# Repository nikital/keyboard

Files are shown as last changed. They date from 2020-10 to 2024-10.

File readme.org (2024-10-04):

#+STARTUP: indent

* Layout
Generated at http://www.keyboard-layout-editor.com/

* Plate
Generated at http://builder.swillkb.com/
- Switch Type: MX
- Stabilizer: Cherry Only

* PCB

** Placement
5.7mm 7.5mm For diodes from pin 1

** Components

*** MCU
ATMEGA32U4-AU

*** PPTC
MF-PSMF020X-2

*** I/O expander
MCP23018-E/SO

*** Resistors (2012/0805)

*** ESD protection
PRTR5V0U2X

* Burn
Load DFU bootloader. When using Arduino as ISP, first burn an Arduino using the
ArduinoISP example sketch. Then wire everything according to comments. Make sure
to use a good 5V source and the the 5V on ICSP (not sure why, but it glitched).
Then run:
#+begin_src sh
avrdude -patmega32u4 -cstk500v1 -P/dev/ttyUSB0 -b19200 -e -U flash:w:dfu/ATMega32U4-usbdevice_dfu-1_0_0.hex:i -U lfuse:w:0b01011110:m -U hfuse:w:0b10011001:m -U efuse:w:0b11000011:m -U lock:w:0b101100:m
#+end_src

If using a USBasp based programmer, use: =-cusbasp=.
#+begin_src sh
avrdude -patmega32u4 -cusbasp -e -U flash:w:dfu/ATMega32U4-usbdevice_dfu-1_0_0.hex:i -U lfuse:w:0b01011110:m -U hfuse:w:0b10011001:m -U efuse:w:0b11000011:m -U lock:w:0b101100:m
#+end_src

Make sure to issue an ~dfu-programmer atmega32u4 erase --force~ to make sure that the flash
is writable.

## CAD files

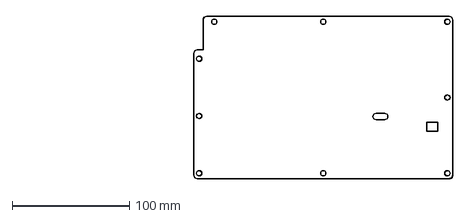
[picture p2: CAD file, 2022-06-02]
plate/slash_production/acryl_1_5_mm/right_acryl_1_5_mm.dxf
372.5 x 138.5 mm

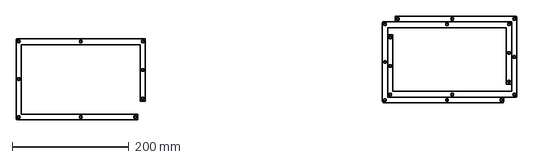
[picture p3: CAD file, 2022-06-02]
plate/slash_production/acryl_4_mm/right_acryl_4_mm.dxf
856.3 x 176.8 mm

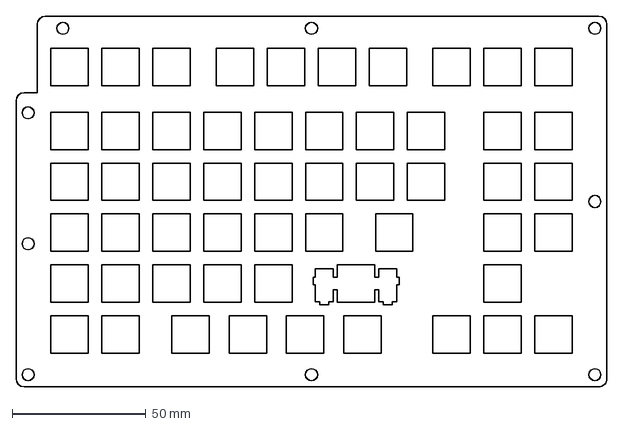
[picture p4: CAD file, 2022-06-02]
plate/slash_production/aluminum_1_5_mm/right_aluminum_1_5_mm.dxf
221.0 x 138.5 mm

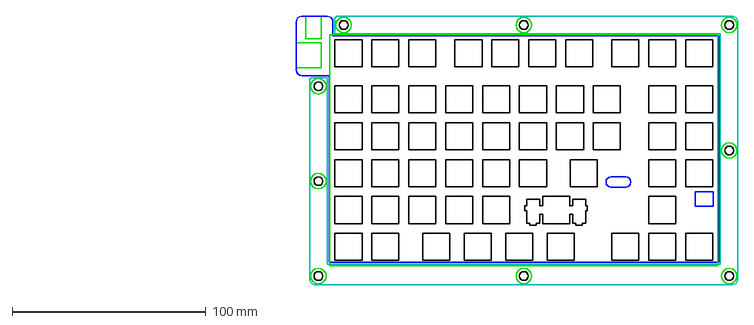
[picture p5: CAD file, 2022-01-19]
plate/slash_right.dxf
372.5 x 138.5 mm

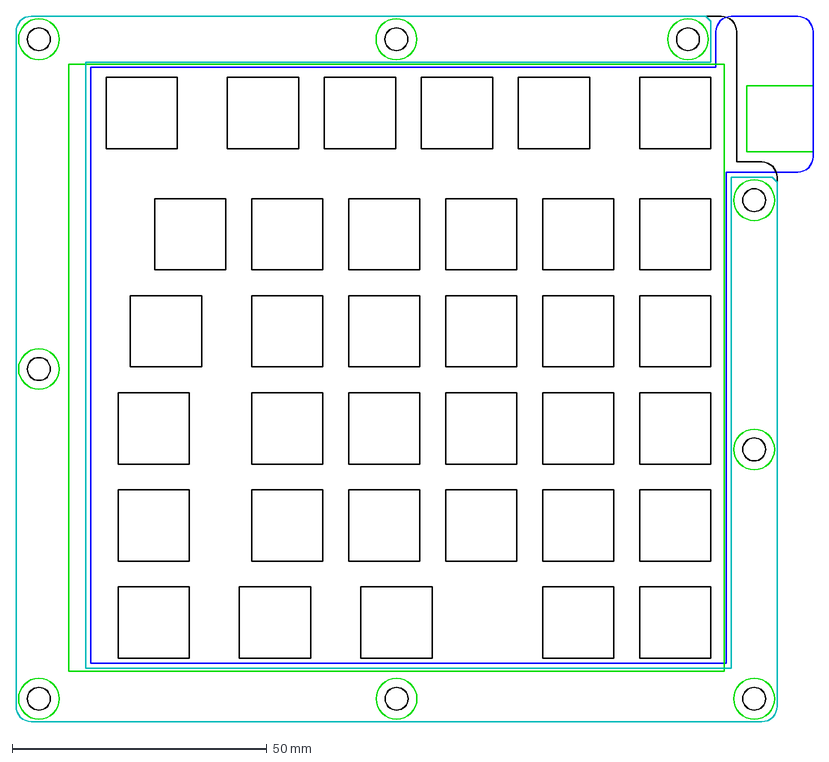
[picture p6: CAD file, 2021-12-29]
plate/slash_left.dxf
156.5 x 138.5 mm

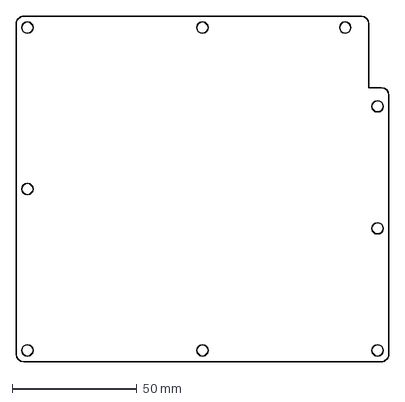
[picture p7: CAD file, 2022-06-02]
plate/slash_production/acryl_1_5_mm/left_acryl_1_5_mm.dxf
149.5 x 138.5 mm

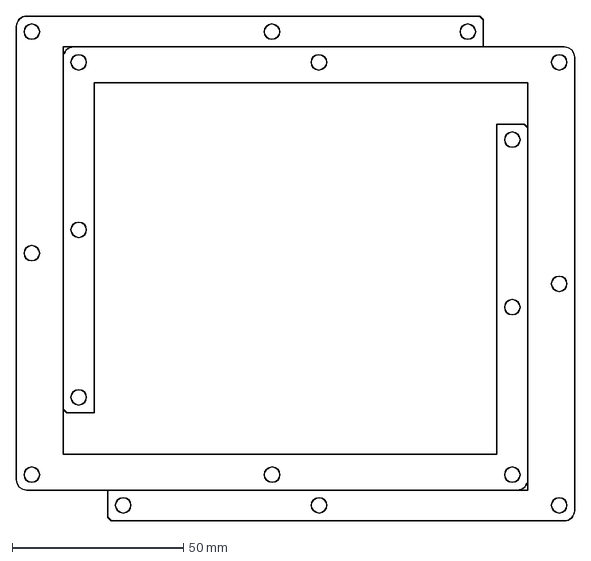
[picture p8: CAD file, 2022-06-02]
plate/slash_production/acryl_4_mm/left_acryl_4_mm.dxf
163.2 x 147.5 mm

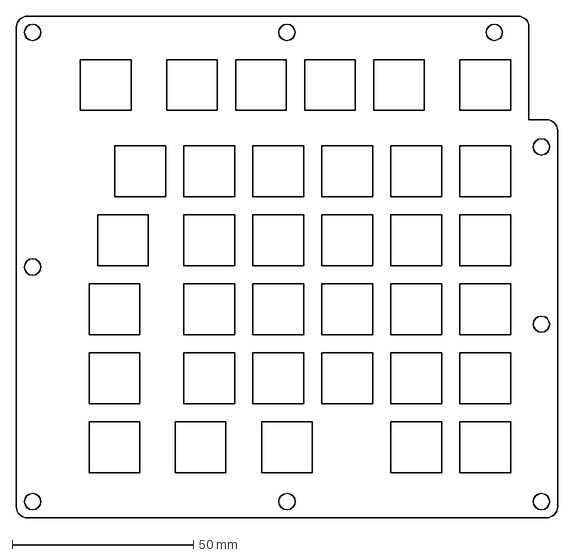
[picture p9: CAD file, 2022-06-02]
plate/slash_production/aluminum_1_5_mm/left_aluminum_1_5_mm.dxf
149.5 x 138.5 mm

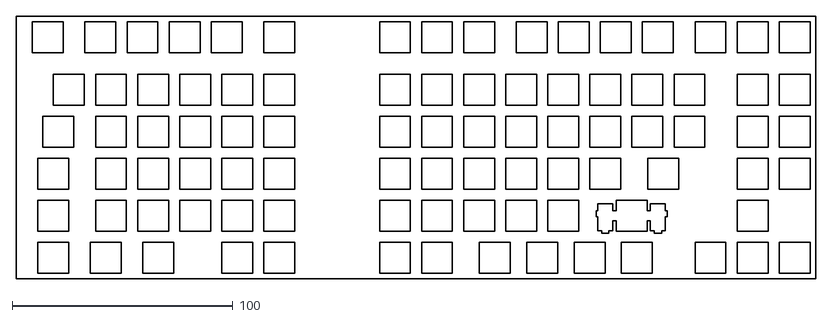
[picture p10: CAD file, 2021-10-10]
plate/slash_swillkb.dxf
361.9 x 119.1

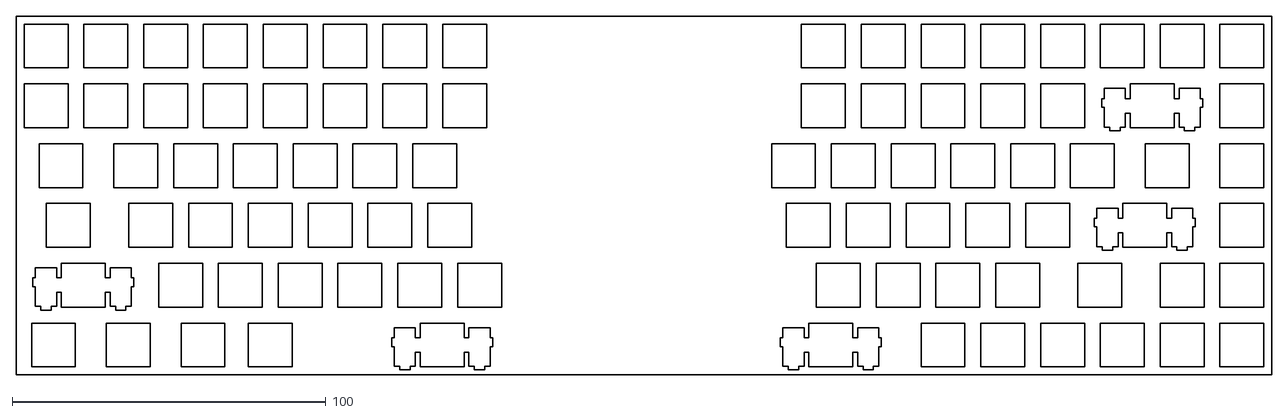
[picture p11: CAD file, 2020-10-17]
plate/swillkb_split_offset.dxf
400.0 x 114.3

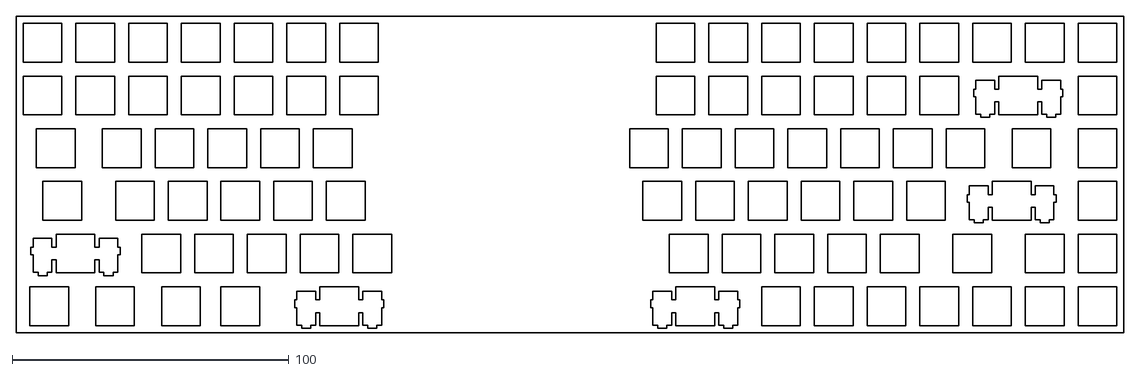
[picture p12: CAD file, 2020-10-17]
plate/swillkb_split.dxf
400.0 x 114.3

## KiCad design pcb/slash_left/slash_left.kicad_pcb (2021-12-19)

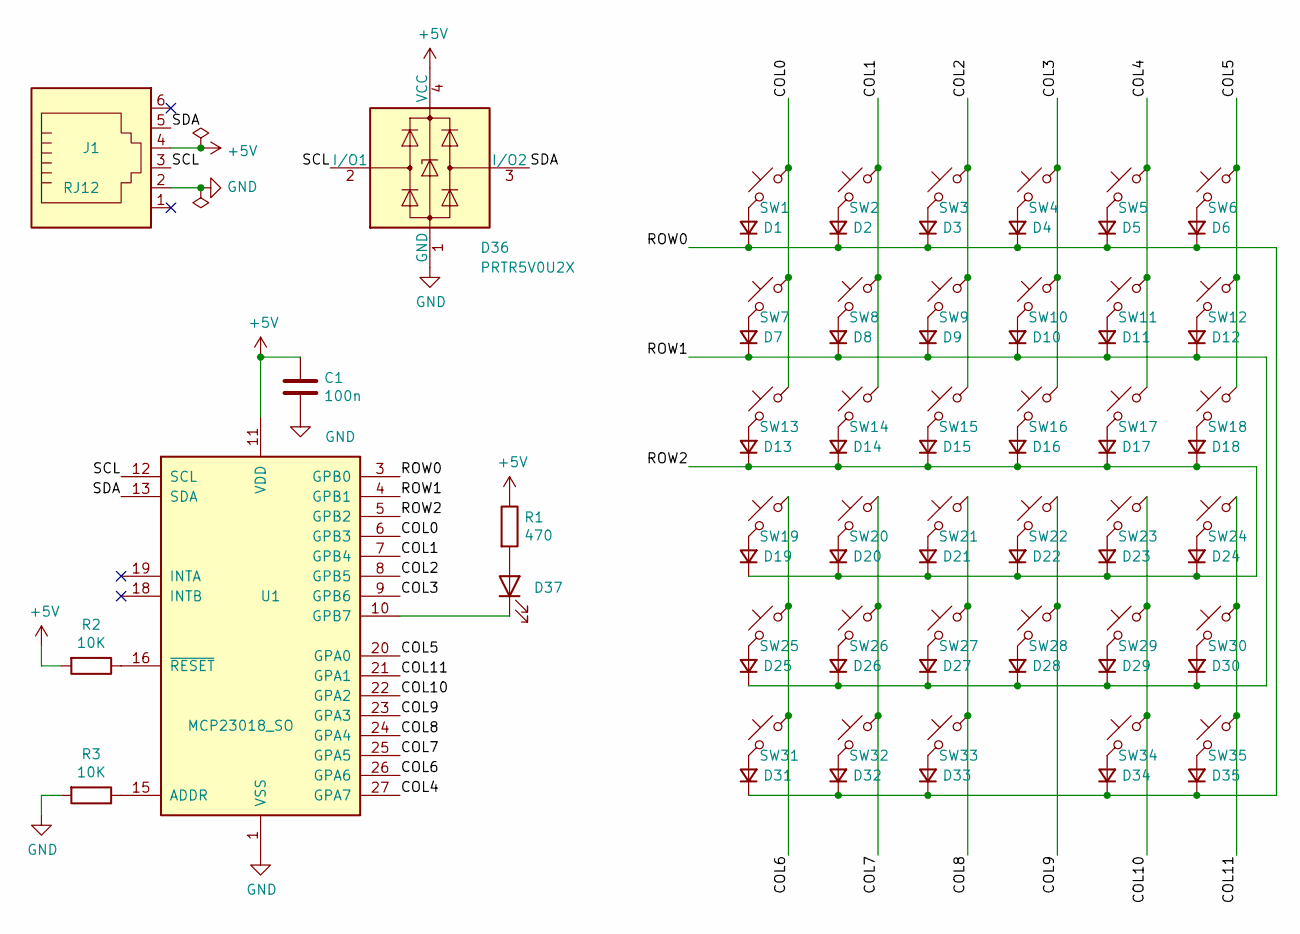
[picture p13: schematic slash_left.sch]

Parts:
C1: 100n; C_0805_2012Metric_Pad1.18x1.45mm_HandSolder
D1, D2, D3, D4, D5, D6, D7, D8, D9, D10, D11, D12, D13, D14, D15, D16, D17, D18, D19, D20, D21, D22, D23, D24, D25, D26, D27, D28, D29, D30, D31, D32, D33, D34, D35: D_Small; D_SOD-123
D36: PRTR5V0U2X; SOT-143
D37: LED; LED_0805_2012Metric_Pad1.15x1.40mm_HandSolder
J1: RJ12; RJ12_Custom1
R1: 470; R_0805_2012Metric_Pad1.20x1.40mm_HandSolder
R2, R3: 10K; R_0805_2012Metric_Pad1.20x1.40mm_HandSolder
SW1, SW2, SW3, SW4, SW5, SW6, SW7, SW8, SW9, SW10, SW11, SW12, SW13, SW14, SW15, SW16, SW17, SW18, SW19, SW20, SW21, SW22, SW23, SW24, SW25, SW26, SW27, SW28, SW29, SW30, SW31, SW32, SW33, SW34, SW35: SW_Push_45deg; Kailh_socket_MX
U1: MCP23018_SO; SOIC-28W_7.5x17.9mm_P1.27mm

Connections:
+5V: C1.1, D36.4 (VCC), J1.4, R1.1, R2.2, U1.11 (VDD)
/COL0: SW1.2, SW7.2, SW13.2, U1.6 (GPB3)
/COL1: SW2.2, SW8.2, SW14.2, U1.7 (GPB4)
/COL2: SW3.2, SW9.2, SW15.2, U1.8 (GPB5)
/COL3: SW4.2, SW10.2, SW16.2, U1.9 (GPB6)
/COL4: SW5.2, SW11.2, SW17.2, U1.27 (GPA7)
/COL5: SW6.2, SW12.2, SW18.2, U1.20 (GPA0)
/COL6: SW19.2, SW25.2, SW31.2, U1.26 (GPA6)
/COL7: SW20.2, SW26.2, SW32.2, U1.25 (GPA5)
/COL8: SW21.2, SW27.2, SW33.2, U1.24 (GPA4)
/COL9: SW22.2, SW28.2, U1.23 (GPA3)
/COL10: SW23.2, SW29.2, SW34.2, U1.22 (GPA2)
/COL11: SW24.2, SW30.2, SW35.2, U1.21 (GPA1)
/ROW0: D1.1 (K), D2.1 (K), D3.1 (K), D4.1 (K), D5.1 (K), D6.1 (K), D31.1 (K), D32.1 (K), D33.1 (K), D34.1 (K), D35.1 (K), U1.3 (GPB0)
/ROW1: D7.1 (K), D8.1 (K), D9.1 (K), D10.1 (K), D11.1 (K), D12.1 (K), D25.1 (K), D26.1 (K), D27.1 (K), D28.1 (K), D29.1 (K), D30.1 (K), U1.4 (GPB1)
/ROW2: D13.1 (K), D14.1 (K), D15.1 (K), D16.1 (K), D17.1 (K), D18.1 (K), D19.1 (K), D20.1 (K), D21.1 (K), D22.1 (K), D23.1 (K), D24.1 (K), U1.5 (GPB2)
/SCL: D36.2 (I/O1), J1.3, U1.12 (SCL)
/SDA: D36.3 (I/O2), J1.5, U1.13 (SDA)
GND: C1.2, D36.1 (GND), J1.2, R3.2, U1.1 (VSS)
unnamed: D1.2 (A), SW1.1
unnamed: D2.2 (A), SW2.1
unnamed: D3.2 (A), SW3.1
unnamed: D4.2 (A), SW4.1
unnamed: D5.2 (A), SW5.1
unnamed: D6.2 (A), SW6.1
unnamed: D7.2 (A), SW7.1
unnamed: D8.2 (A), SW8.1
unnamed: D9.2 (A), SW9.1
unnamed: D10.2 (A), SW10.1
unnamed: D11.2 (A), SW11.1
unnamed: D12.2 (A), SW12.1
unnamed: D13.2 (A), SW13.1
unnamed: D14.2 (A), SW14.1
unnamed: D15.2 (A), SW15.1
unnamed: D16.2 (A), SW16.1
unnamed: D17.2 (A), SW17.1
unnamed: D18.2 (A), SW18.1
unnamed: D19.2 (A), SW19.1
unnamed: D20.2 (A), SW20.1
unnamed: D21.2 (A), SW21.1
unnamed: D22.2 (A), SW22.1
unnamed: D23.2 (A), SW23.1
unnamed: D24.2 (A), SW24.1
unnamed: D25.2 (A), SW25.1
unnamed: D26.2 (A), SW26.1
unnamed: D27.2 (A), SW27.1
unnamed: D28.2 (A), SW28.1
unnamed: D29.2 (A), SW29.1
unnamed: D30.2 (A), SW30.1
unnamed: D31.2 (A), SW31.1
unnamed: D32.2 (A), SW32.1
unnamed: D33.2 (A), SW33.1
unnamed: D34.2 (A), SW34.1
unnamed: D35.2 (A), SW35.1
unnamed: D37.1 (K), U1.10 (GPB7)
unnamed: D37.2 (A), R1.2
unnamed: R2.1, U1.16 (~RESET)
unnamed: R3.1, U1.15 (ADDR)

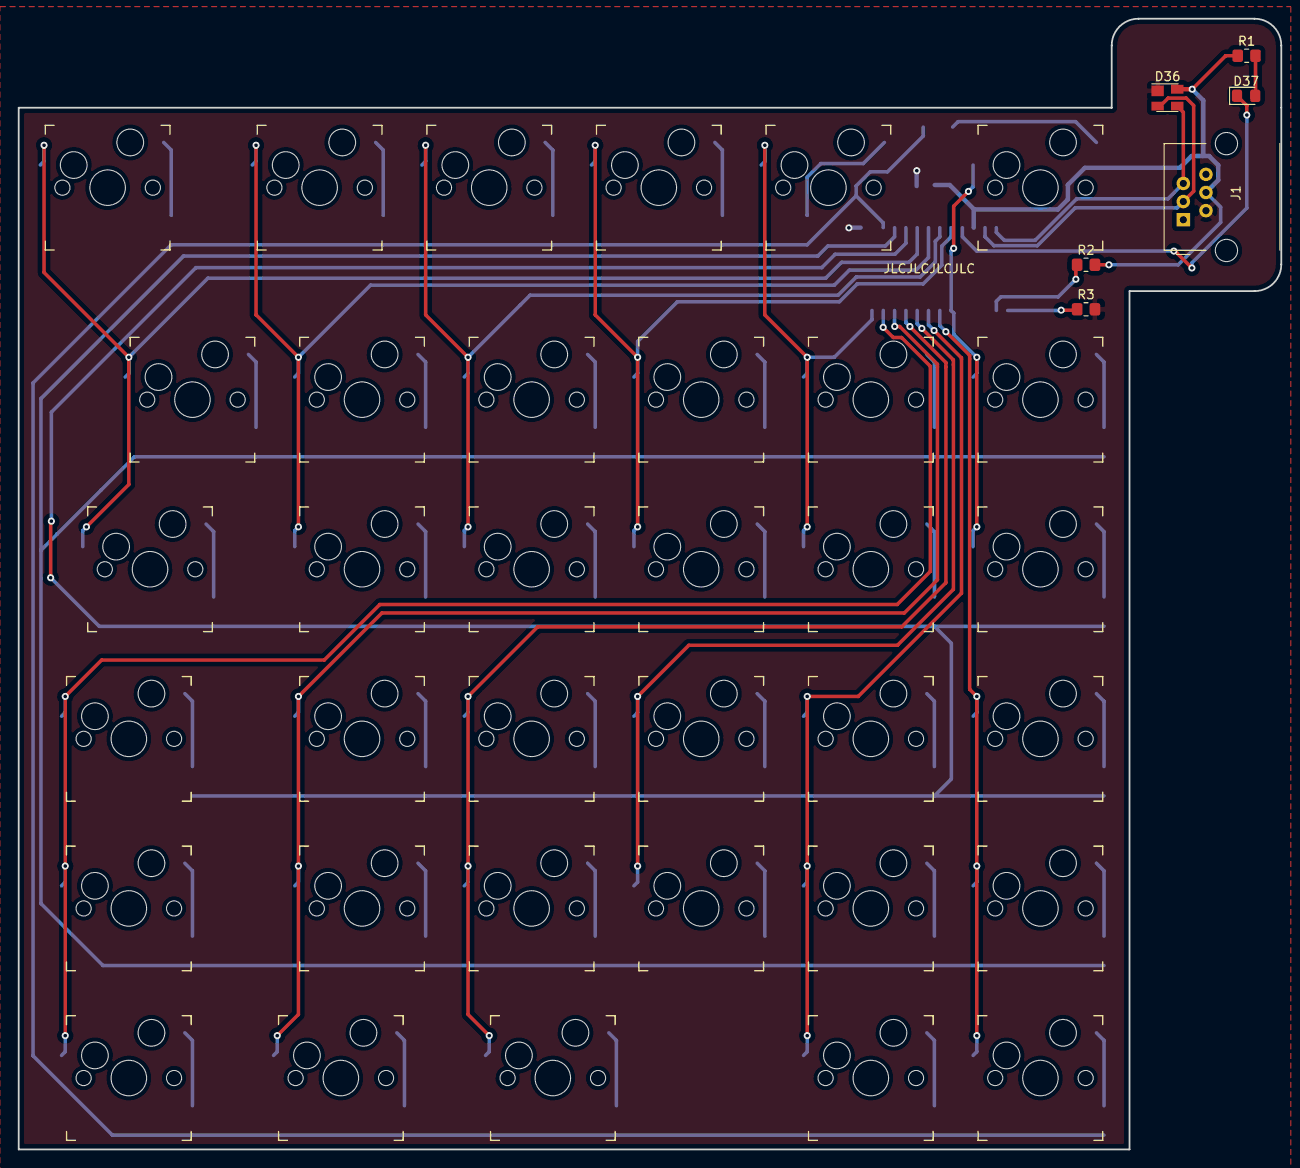
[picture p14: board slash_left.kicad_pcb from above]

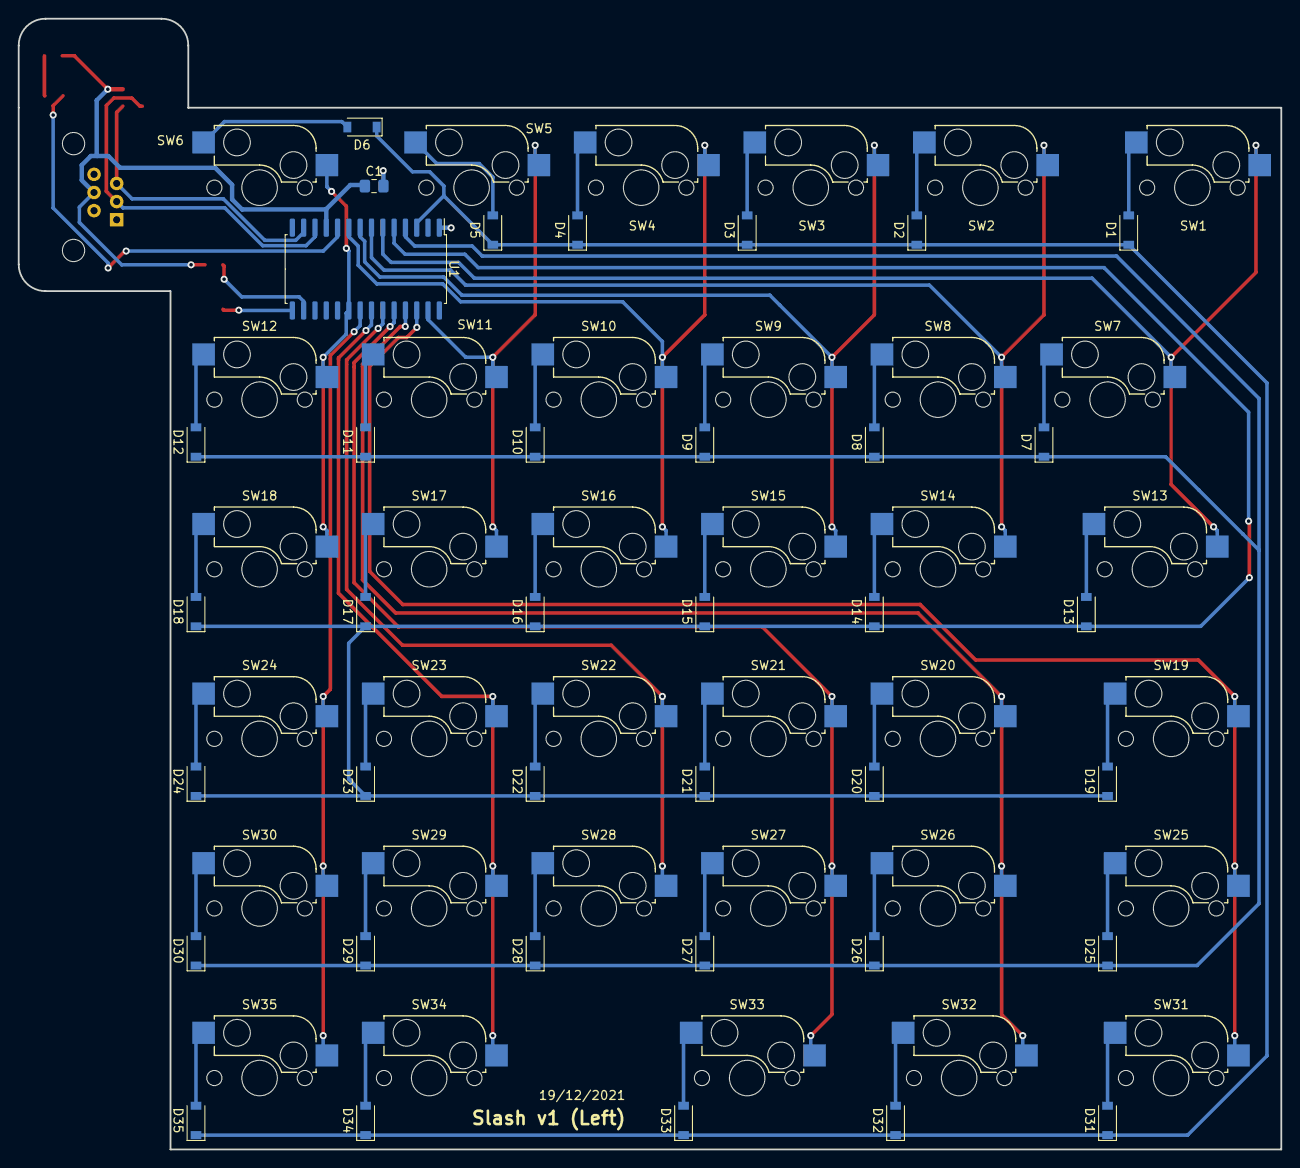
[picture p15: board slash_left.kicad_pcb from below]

Board: 2 copper layers, 141.8 x 127.0 mm, 78 parts (37 on the bottom side), 58 nets.

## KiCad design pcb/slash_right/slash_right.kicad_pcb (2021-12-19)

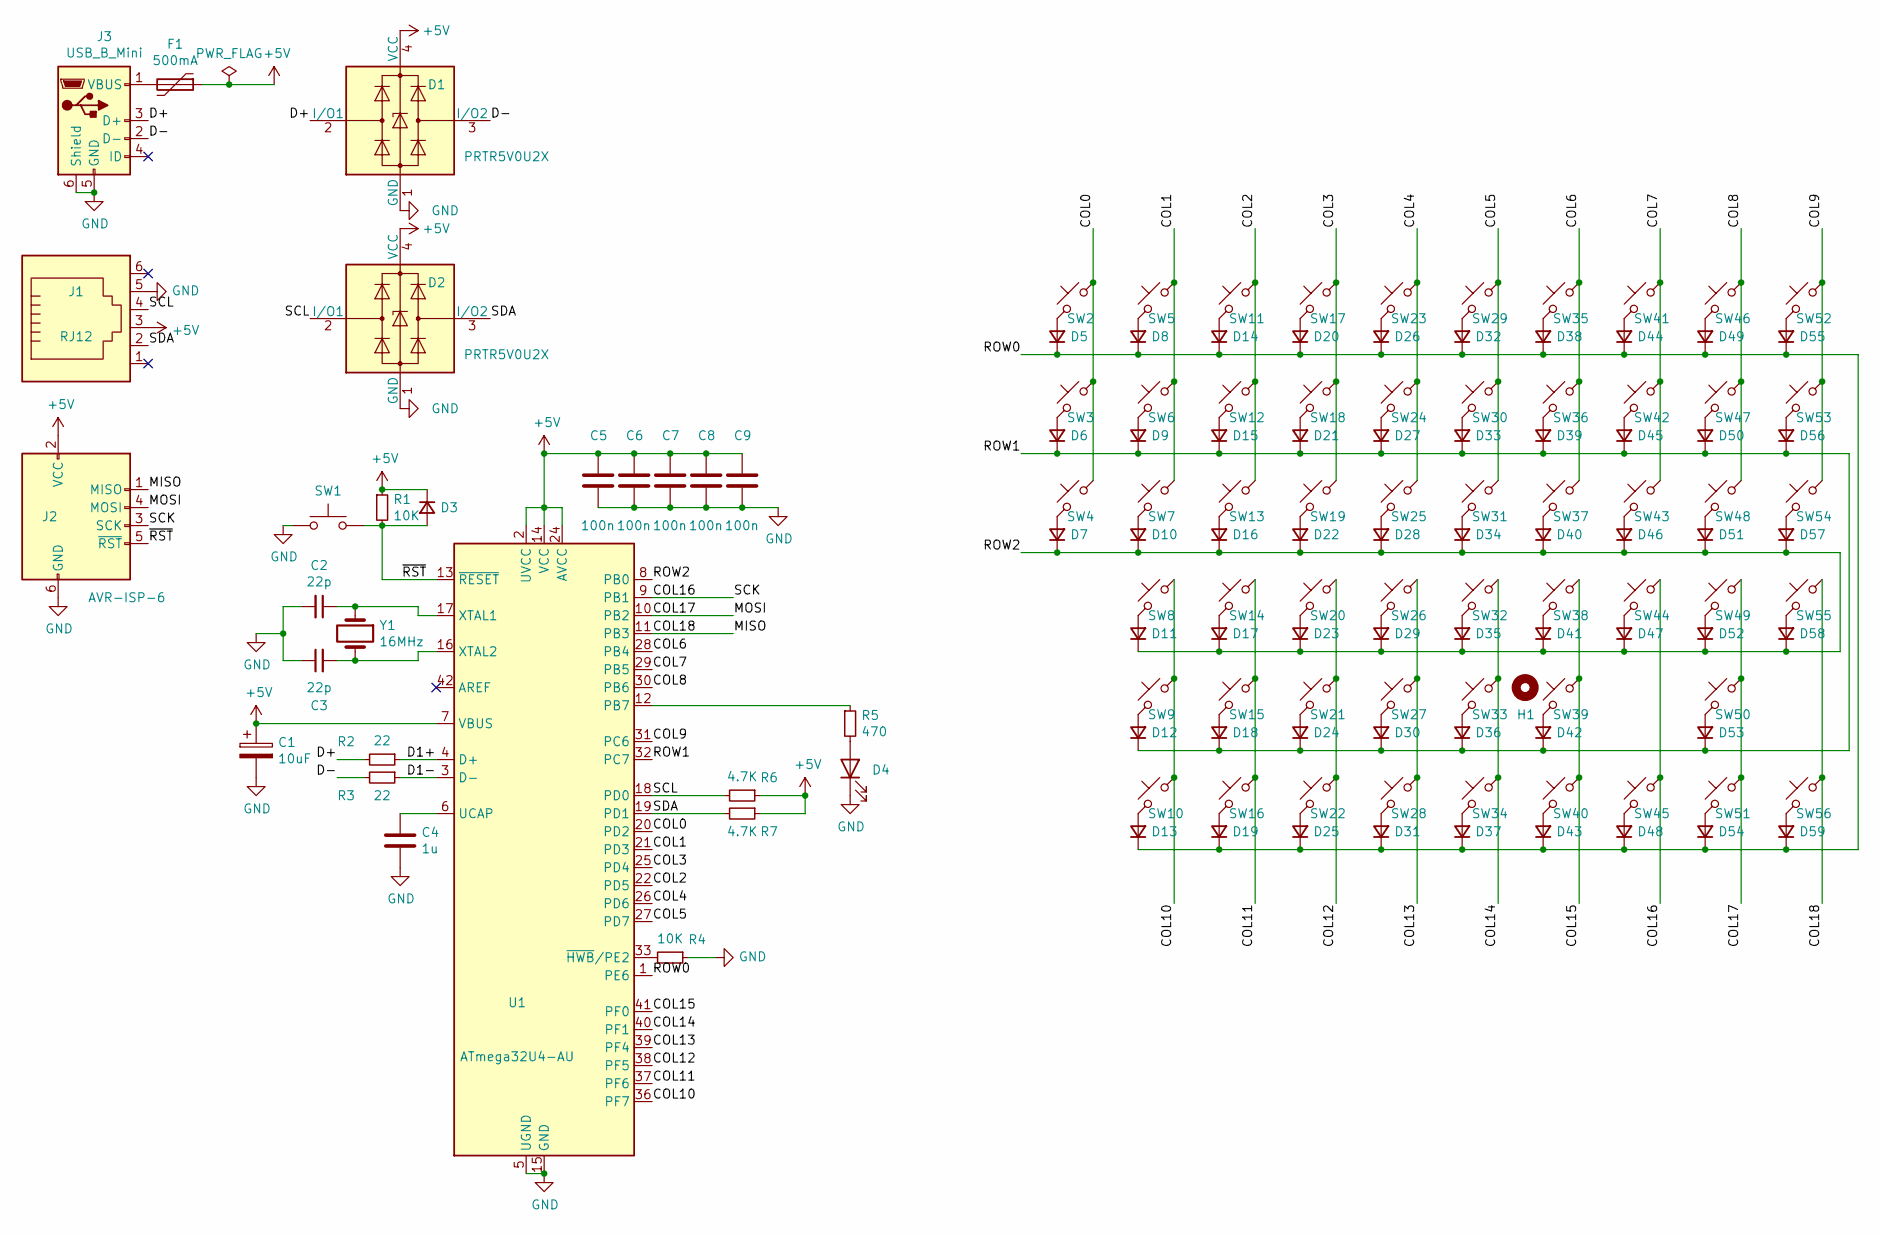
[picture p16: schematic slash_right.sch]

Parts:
C1: 10uF; CP_EIA-3216-18_Kemet-A_Pad1.58x1.35mm_HandSolder
C2, C3: 22p; C_0805_2012Metric_Pad1.18x1.45mm_HandSolder
C4: 1u; C_0805_2012Metric_Pad1.18x1.45mm_HandSolder
C5, C6, C7, C8, C9: 100n; C_0805_2012Metric_Pad1.18x1.45mm_HandSolder
D1, D2: PRTR5V0U2X; SOT-143
D3, D5, D6, D7, D8, D9, D10, D11, D12, D13, D14, D15, D16, D17, D18, D19, D20, D21, D22, D23, D24, D25, D26, D27, D28, D29, D30, D31, D32, D33, D34, D35, D36, D37, D38, D39, D40, D41, D42, D43, D44, D45, D46, D47, D48, D49, D50, D51, D52, D53, D54, D55, D56, D57, D58, D59: D_Small; D_SOD-123
D4: LED; LED_0805_2012Metric_Pad1.15x1.40mm_HandSolder
F1: 500mA; Fuse_0805_2012Metric_Pad1.15x1.40mm_HandSolder
H1: MountingHole; Stabilizer_MX_2u
J1: RJ12; RJ12_Custom1
J2: AVR-ISP-6; PinHeader_2x03_P2.54mm_Vertical
J3: USB_B_Mini; USB_Mini-B_Custom1_Horizontal
R1, R4: 10K; R_0805_2012Metric_Pad1.20x1.40mm_HandSolder
R2, R3: 22; R_0805_2012Metric_Pad1.20x1.40mm_HandSolder
R5: 470; R_0805_2012Metric_Pad1.20x1.40mm_HandSolder
R6, R7: 4.7K; R_0805_2012Metric_Pad1.20x1.40mm_HandSolder
SW1: SW_Push; SW_PUSH_6mm_H4.3mm
SW2, SW3, SW4, SW5, SW6, SW7, SW8, SW9, SW10, SW11, SW12, SW13, SW14, SW15, SW16, SW17, SW18, SW19, SW20, SW21, SW22, SW23, SW24, SW25, SW26, SW27, SW28, SW29, SW30, SW31, SW32, SW33, SW34, SW35, SW36, SW37, SW38, SW39, SW40, SW41, SW42, SW43, SW44, SW45, SW46, SW47, SW48, SW49, SW50, SW51, SW52, SW53, SW54, SW55, SW56: SW_Push_45deg; Kailh_socket_MX
U1: ATmega32U4-AU; TQFP-44_10x10mm_P0.8mm
Y1: 16MHz; Crystal_HC49-U_Vertical

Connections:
+5V: C1.1, C5.1, C6.1, C7.1, C8.1, C9.1, D1.4 (VCC), D2.4 (VCC), D3.1 (K), F1.1, J1.3, J2.2 (VCC), R1.1, R6.1, R7.1, U1.2 (UVCC), U1.7 (VBUS), U1.14 (VCC), U1.24 (AVCC), U1.34 (VCC), U1.44 (AVCC)
/COL0: SW2.2, SW3.2, SW4.2, U1.20 (PD2)
/COL1: SW5.2, SW6.2, SW7.2, U1.21 (PD3)
/COL2: SW11.2, SW12.2, SW13.2, U1.22 (PD5)
/COL3: SW17.2, SW18.2, SW19.2, U1.25 (PD4)
/COL4: SW23.2, SW24.2, SW25.2, U1.26 (PD6)
/COL5: SW29.2, SW30.2, SW31.2, U1.27 (PD7)
/COL6: SW35.2, SW36.2, SW37.2, U1.28 (PB4)
/COL7: SW41.2, SW42.2, SW43.2, U1.29 (PB5)
/COL8: SW46.2, SW47.2, SW48.2, U1.30 (PB6)
/COL9: SW52.2, SW53.2, SW54.2, U1.31 (PC6)
/COL10: SW8.2, SW9.2, SW10.2, U1.36 (PF7)
/COL11: SW14.2, SW15.2, SW16.2, U1.37 (PF6)
/COL12: SW20.2, SW21.2, SW22.2, U1.38 (PF5)
/COL13: SW26.2, SW27.2, SW28.2, U1.39 (PF4)
/COL14: SW32.2, SW33.2, SW34.2, U1.40 (PF1)
/COL15: SW38.2, SW39.2, SW40.2, U1.41 (PF0)
/COL16: J2.3 (SCK), SW44.2, SW45.2, U1.9 (PB1)
/COL17: J2.4 (MOSI), SW49.2, SW50.2, SW51.2, U1.10 (PB2)
/COL18: J2.1 (MISO), SW55.2, SW56.2, U1.11 (PB3)
/D1+: R2.1, U1.4 (D+)
/D1-: R3.1, U1.3 (D-)
/D+: D1.2 (I/O1), J3.3 (D+), R2.2
/D-: D1.3 (I/O2), J3.2 (D-), R3.2
/ROW0: D5.1 (K), D8.1 (K), D13.1 (K), D14.1 (K), D19.1 (K), D20.1 (K), D25.1 (K), D26.1 (K), D31.1 (K), D32.1 (K), D37.1 (K), D38.1 (K), D43.1 (K), D44.1 (K), D48.1 (K), D49.1 (K), D54.1 (K), D55.1 (K), D59.1 (K), U1.1 (PE6)
/ROW1: D6.1 (K), D9.1 (K), D12.1 (K), D15.1 (K), D18.1 (K), D21.1 (K), D24.1 (K), D27.1 (K), D30.1 (K), D33.1 (K), D36.1 (K), D39.1 (K), D42.1 (K), D45.1 (K), D50.1 (K), D53.1 (K), D56.1 (K), U1.32 (PC7)
/ROW2: D7.1 (K), D10.1 (K), D11.1 (K), D16.1 (K), D17.1 (K), D22.1 (K), D23.1 (K), D28.1 (K), D29.1 (K), D34.1 (K), D35.1 (K), D40.1 (K), D41.1 (K), D46.1 (K), D47.1 (K), D51.1 (K), D52.1 (K), D57.1 (K), D58.1 (K), U1.8 (PB0)
/SCL: D2.2 (I/O1), J1.4, R6.2, U1.18 (PD0)
/SDA: D2.3 (I/O2), J1.2, R7.2, U1.19 (PD1)
/~RST: D3.2 (A), J2.5 (~RST), R1.2, SW1.2, U1.13 (~RESET)
GND: C1.2, C2.2, C3.1, C4.2, C5.2, C6.2, C7.2, C8.2, C9.2, D1.1 (GND), D2.1 (GND), D4.1 (K), J1.5, J2.6 (GND), J3.5 (GND), J3.6 (Shield), R4.1, SW1.1, U1.5 (UGND), U1.15 (GND), U1.23 (GND), U1.35 (GND), U1.43 (GND)
unnamed: C2.1, U1.17 (XTAL1), Y1.1
unnamed: C3.2, U1.16 (XTAL2), Y1.2
unnamed: C4.1, U1.6 (UCAP)
unnamed: D4.2 (A), R5.2
unnamed: D5.2 (A), SW2.1
unnamed: D6.2 (A), SW3.1
unnamed: D7.2 (A), SW4.1
unnamed: D8.2 (A), SW5.1
unnamed: D9.2 (A), SW6.1
unnamed: D10.2 (A), SW7.1
unnamed: D11.2 (A), SW8.1
unnamed: D12.2 (A), SW9.1
unnamed: D13.2 (A), SW10.1
unnamed: D14.2 (A), SW11.1
unnamed: D15.2 (A), SW12.1
unnamed: D16.2 (A), SW13.1
unnamed: D17.2 (A), SW14.1
unnamed: D18.2 (A), SW15.1
unnamed: D19.2 (A), SW16.1
unnamed: D20.2 (A), SW17.1
unnamed: D21.2 (A), SW18.1
unnamed: D22.2 (A), SW19.1
unnamed: D23.2 (A), SW20.1
unnamed: D24.2 (A), SW21.1
unnamed: D25.2 (A), SW22.1
unnamed: D26.2 (A), SW23.1
unnamed: D27.2 (A), SW24.1
unnamed: D28.2 (A), SW25.1
unnamed: D29.2 (A), SW26.1
unnamed: D30.2 (A), SW27.1
unnamed: D31.2 (A), SW28.1
unnamed: D32.2 (A), SW29.1
unnamed: D33.2 (A), SW30.1
unnamed: D34.2 (A), SW31.1
unnamed: D35.2 (A), SW32.1
unnamed: D36.2 (A), SW33.1
unnamed: D37.2 (A), SW34.1
unnamed: D38.2 (A), SW35.1
unnamed: D39.2 (A), SW36.1
unnamed: D40.2 (A), SW37.1
unnamed: D41.2 (A), SW38.1
unnamed: D42.2 (A), SW39.1
unnamed: D43.2 (A), SW40.1
unnamed: D44.2 (A), SW41.1
unnamed: D45.2 (A), SW42.1
unnamed: D46.2 (A), SW43.1
unnamed: D47.2 (A), SW44.1
unnamed: D48.2 (A), SW45.1
unnamed: D49.2 (A), SW46.1
unnamed: D50.2 (A), SW47.1
unnamed: D51.2 (A), SW48.1
unnamed: D52.2 (A), SW49.1
unnamed: D53.2 (A), SW50.1
unnamed: D54.2 (A), SW51.1
unnamed: D55.2 (A), SW52.1
unnamed: D56.2 (A), SW53.1
unnamed: D57.2 (A), SW54.1
unnamed: D58.2 (A), SW55.1
unnamed: D59.2 (A), SW56.1
unnamed: F1.2, J3.1 (VBUS)
unnamed: R4.2, U1.33 (~HWB~/PE2)
unnamed: R5.1, U1.12 (PB7)

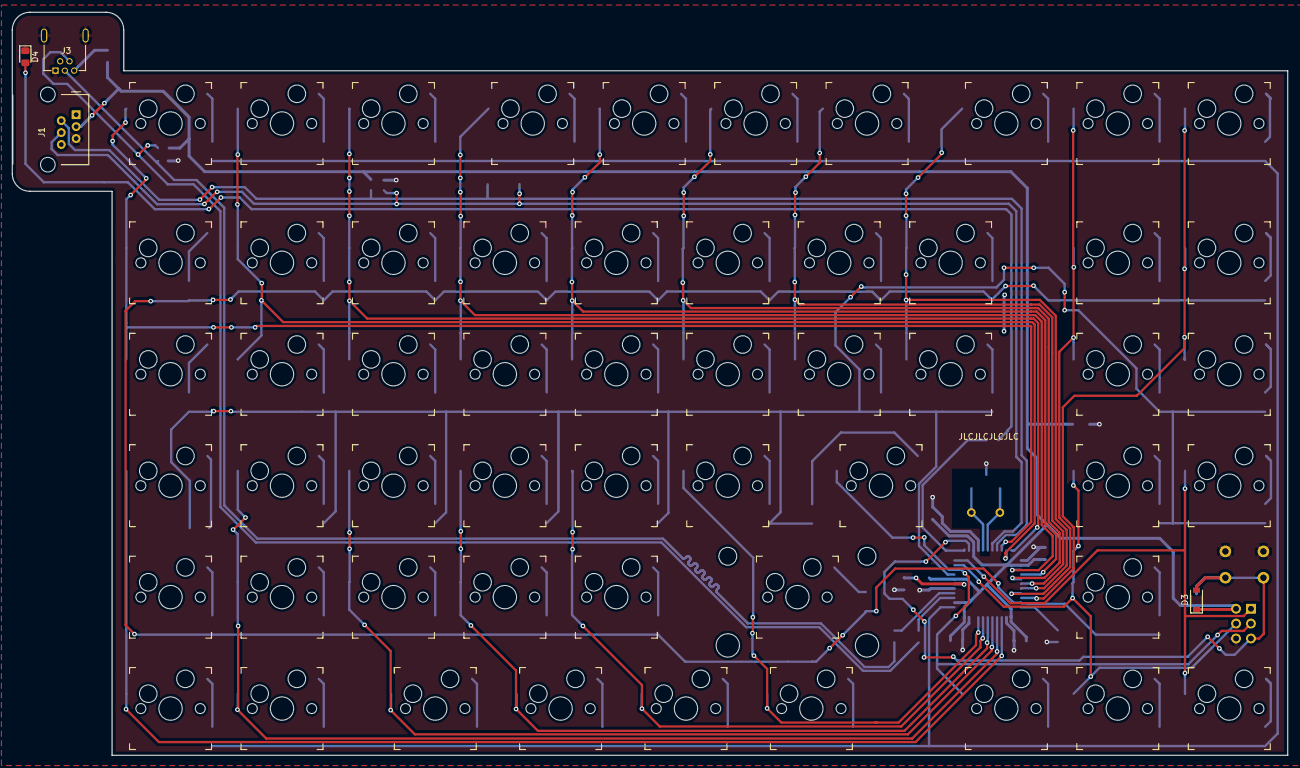
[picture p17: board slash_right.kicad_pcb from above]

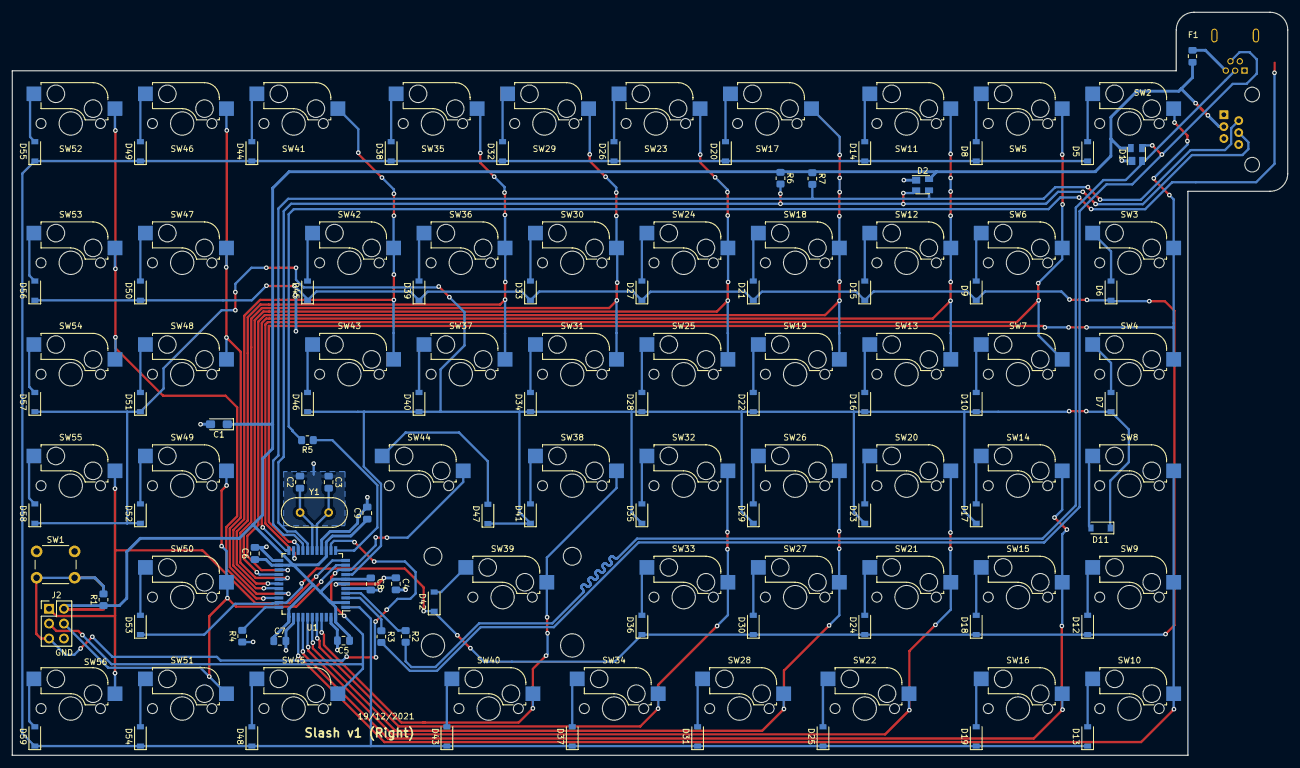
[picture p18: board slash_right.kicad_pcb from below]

Board: 2 copper layers, 218.0 x 127.0 mm, 138 parts (78 on the bottom side), 93 nets.

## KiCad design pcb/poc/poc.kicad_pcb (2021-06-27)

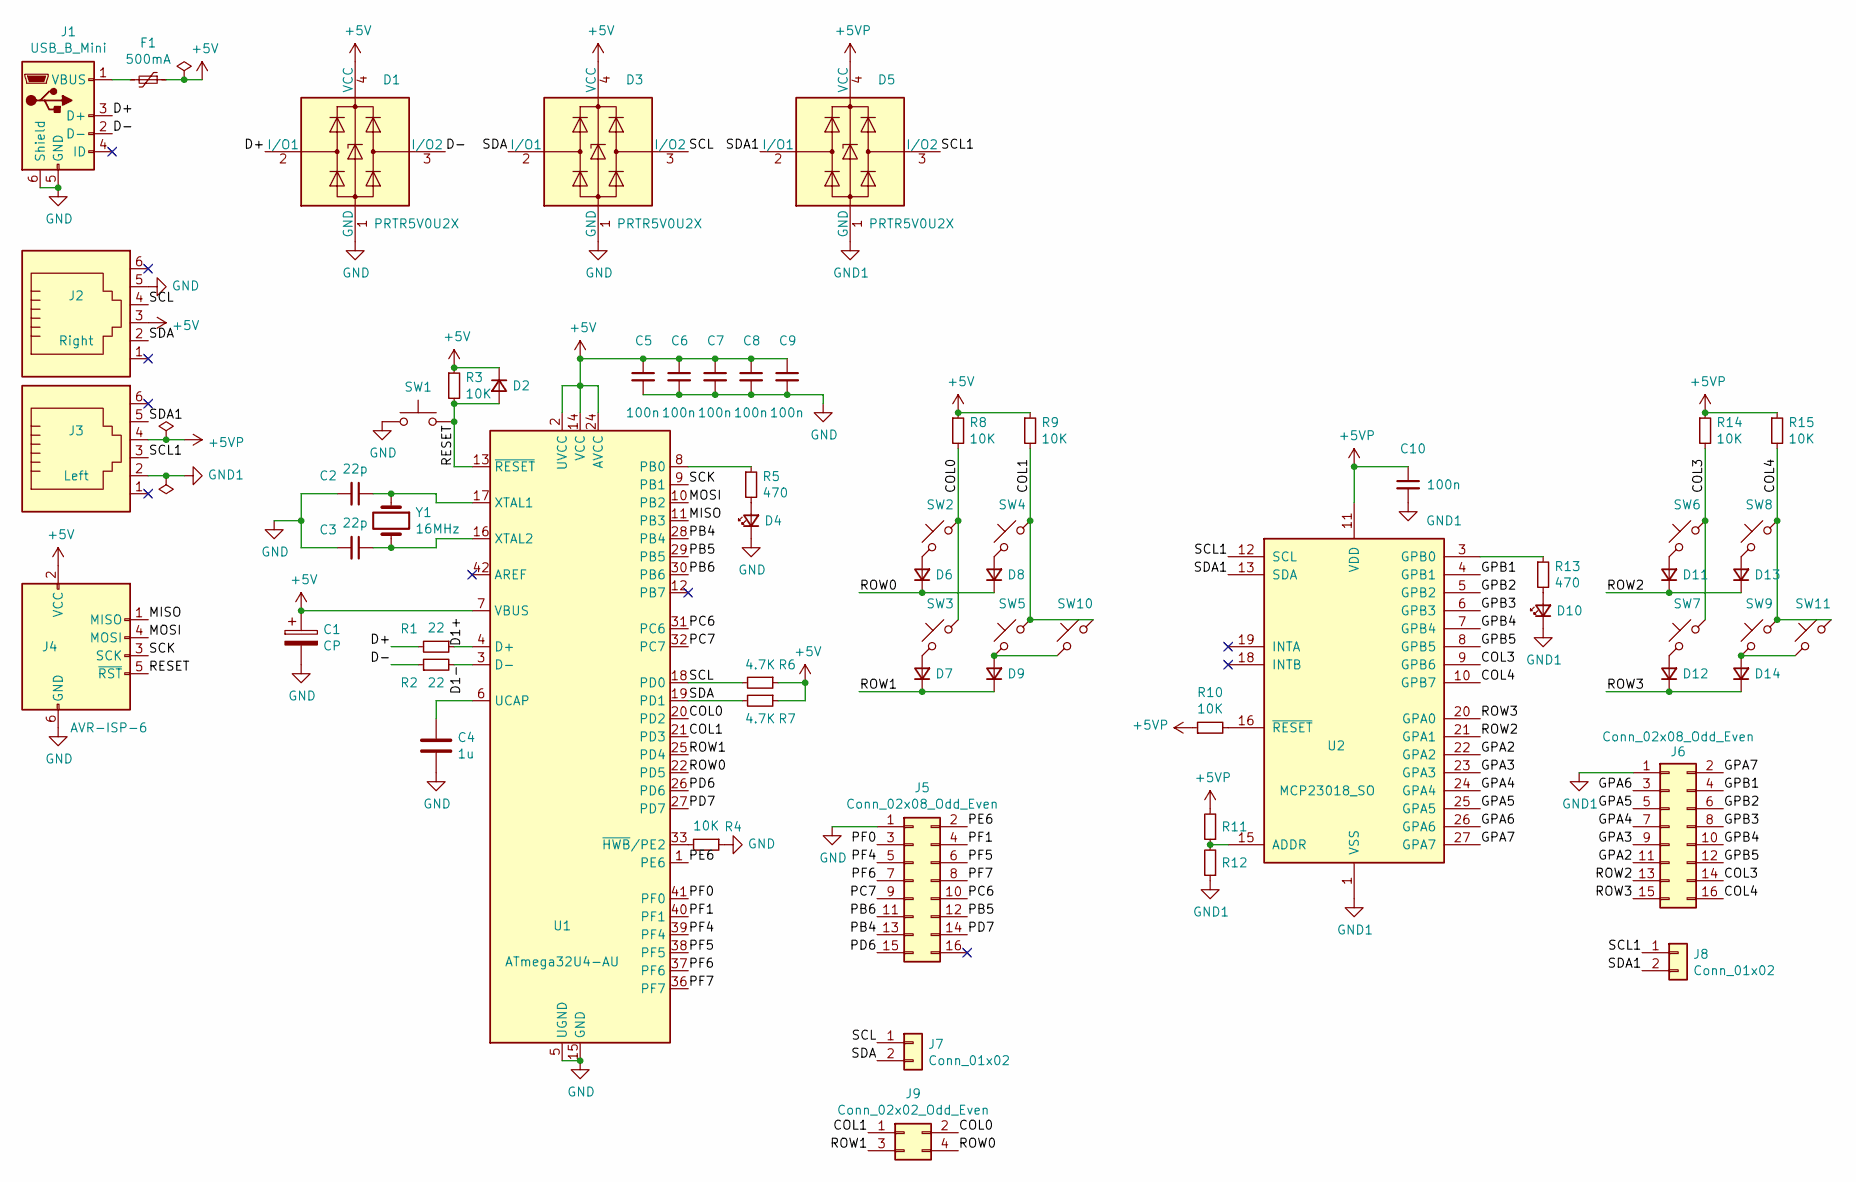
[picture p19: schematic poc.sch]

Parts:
C1: CP; CP_EIA-3216-18_Kemet-A_Pad1.58x1.35mm_HandSolder
C2, C3: 22p; C_0805_2012Metric_Pad1.18x1.45mm_HandSolder
C4: 1u; C_0805_2012Metric_Pad1.18x1.45mm_HandSolder
C5, C6, C7, C8, C9, C10: 100n; C_0805_2012Metric_Pad1.18x1.45mm_HandSolder
D1, D3, D5: PRTR5V0U2X; SOT-143
D2, D6, D7, D8, D9, D11, D12, D13, D14: D_Small; D_SOD-123
D4, D10: LED_Small; LED_0805_2012Metric_Pad1.15x1.40mm_HandSolder
F1: 500mA; Fuse_0805_2012Metric_Pad1.15x1.40mm_HandSolder
J1: USB_B_Mini; USB_Mini-B_Custom1_Horizontal
J2: Right; RJ12_Custom1
J3: Left; RJ12_Custom1
J4: AVR-ISP-6; PinHeader_2x03_P2.54mm_Vertical
J5: Conn_02x08_Odd_Even; PinSocket_2x08_P2.54mm_Vertical
J6: Conn_02x08_Odd_Even; PinHeader_2x08_P2.54mm_Vertical
J7, J8: Conn_01x02; PinHeader_1x02_P2.54mm_Vertical
J9: Conn_02x02_Odd_Even; PinSocket_2x02_P2.54mm_Vertical
R1, R2: 22; R_0805_2012Metric_Pad1.20x1.40mm_HandSolder
R3, R4, R8, R9, R10, R14, R15: 10K; R_0805_2012Metric_Pad1.20x1.40mm_HandSolder
R5, R13: 470; R_0805_2012Metric_Pad1.20x1.40mm_HandSolder
R6, R7: 4.7K; R_0805_2012Metric_Pad1.20x1.40mm_HandSolder
R11, R12: R_Small; R_0805_2012Metric_Pad1.20x1.40mm_HandSolder
SW1: SW_Push; SW_PUSH_6mm_H4.3mm
SW2, SW3, SW4, SW5, SW6, SW7, SW8, SW9: SW_Push_45deg; SW_PUSH_6mm_H4.3mm
SW10, SW11: SW_Push_45deg; SW_Cherry_MX_1.00u_PCB
U1: ATmega32U4-AU; TQFP-44_10x10mm_P0.8mm
U2: MCP23018_SO; SOIC-28W_7.5x17.9mm_P1.27mm
Y1: 16MHz; Crystal_HC49-U_Vertical

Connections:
+5V: C1.1, C5.1, C6.1, C7.1, C8.1, C9.1, D1.4 (VCC), D2.1 (K), D3.4 (VCC), F1.1, J2.3, J4.2 (VCC), R3.1, R6.1, R7.1, R8.1, R9.1, U1.2 (UVCC), U1.7 (VBUS), U1.14 (VCC), U1.24 (AVCC), U1.34 (VCC), U1.44 (AVCC)
+5VP: C10.1, D5.4 (VCC), J3.4, R10.1, R11.2, R14.1, R15.1, U2.11 (VDD)
/COL0: J9.2, R8.2, SW2.1, SW3.1, U1.20 (PD2)
/COL1: J9.1, R9.2, SW4.1, SW5.1, SW10.1, U1.21 (PD3)
/COL3: J6.14, R14.2, SW6.1, SW7.1, U2.9 (GPB6)
/COL4: J6.16, R15.2, SW8.1, SW9.1, SW11.1, U2.10 (GPB7)
/D1+: R1.1, U1.4 (D+)
/D1-: R2.2, U1.3 (D-)
/D+: D1.2 (I/O1), J1.3 (D+), R1.2
/D-: D1.3 (I/O2), J1.2 (D-), R2.1
/GPA2: J6.11, U2.22 (GPA2)
/GPA3: J6.9, U2.23 (GPA3)
/GPA4: J6.7, U2.24 (GPA4)
/GPA5: J6.5, U2.25 (GPA5)
/GPA6: J6.3, U2.26 (GPA6)
/GPA7: J6.2, U2.27 (GPA7)
/GPB1: J6.4, U2.4 (GPB1)
/GPB2: J6.6, U2.5 (GPB2)
/GPB3: J6.8, U2.6 (GPB3)
/GPB4: J6.10, U2.7 (GPB4)
/GPB5: J6.12, U2.8 (GPB5)
/MISO: J4.1 (MISO), U1.11 (PB3)
/MOSI: J4.4 (MOSI), U1.10 (PB2)
/PB4: J5.13, U1.28 (PB4)
/PB5: J5.12, U1.29 (PB5)
/PB6: J5.11, U1.30 (PB6)
/PC6: J5.10, U1.31 (PC6)
/PC7: J5.9, U1.32 (PC7)
/PD6: J5.15, U1.26 (PD6)
/PD7: J5.14, U1.27 (PD7)
/PE6: J5.2, U1.1 (PE6)
/PF0: J5.3, U1.41 (PF0)
/PF1: J5.4, U1.40 (PF1)
/PF4: J5.5, U1.39 (PF4)
/PF5: J5.6, U1.38 (PF5)
/PF6: J5.7, U1.37 (PF6)
/PF7: J5.8, U1.36 (PF7)
/RESET: D2.2 (A), J4.5 (~RST), R3.2, SW1.2, U1.13 (~RESET)
/ROW0: D6.1 (K), D8.1 (K), J9.4, U1.22 (PD5)
/ROW1: D7.1 (K), D9.1 (K), J9.3, U1.25 (PD4)
/ROW2: D11.1 (K), D13.1 (K), J6.13, U2.21 (GPA1)
/ROW3: D12.1 (K), D14.1 (K), J6.15, U2.20 (GPA0)
/SCK: J4.3 (SCK), U1.9 (PB1)
/SCL: D3.3 (I/O2), J2.4, J7.1, R6.2, U1.18 (PD0)
/SCL1: D5.3 (I/O2), J3.3, J8.1, U2.12 (SCL)
/SDA: D3.2 (I/O1), J2.2, J7.2, R7.2, U1.19 (PD1)
/SDA1: D5.2 (I/O1), J3.5, J8.2, U2.13 (SDA)
GND: C1.2, C2.2, C3.2, C4.2, C5.2, C6.2, C7.2, C8.2, C9.2, D1.1 (GND), D3.1 (GND), D4.1 (K), J1.5 (GND), J1.6 (Shield), J2.5, J4.6 (GND), J5.1, R4.1, SW1.1, U1.5 (UGND), U1.15 (GND), U1.23 (GND), U1.35 (GND), U1.43 (GND)
GND1: C10.2, D5.1 (GND), D10.1 (K), J3.2, J6.1, R12.1, U2.1 (VSS)
unnamed: C2.1, U1.17 (XTAL1), Y1.1
unnamed: C3.1, U1.16 (XTAL2), Y1.2
unnamed: C4.1, U1.6 (UCAP)
unnamed: D4.2 (A), R5.2
unnamed: D6.2 (A), SW2.2
unnamed: D7.2 (A), SW3.2
unnamed: D8.2 (A), SW4.2
unnamed: D9.2 (A), SW5.2, SW10.2
unnamed: D10.2 (A), R13.2
unnamed: D11.2 (A), SW6.2
unnamed: D12.2 (A), SW7.2
unnamed: D13.2 (A), SW8.2
unnamed: D14.2 (A), SW9.2, SW11.2
unnamed: F1.2, J1.1 (VBUS)
unnamed: R4.2, U1.33 (~HWB~/PE2)
unnamed: R5.1, U1.8 (PB0)
unnamed: R10.2, U2.16 (~RESET)
unnamed: R11.1, R12.2, U2.15 (ADDR)
unnamed: R13.1, U2.3 (GPB0)

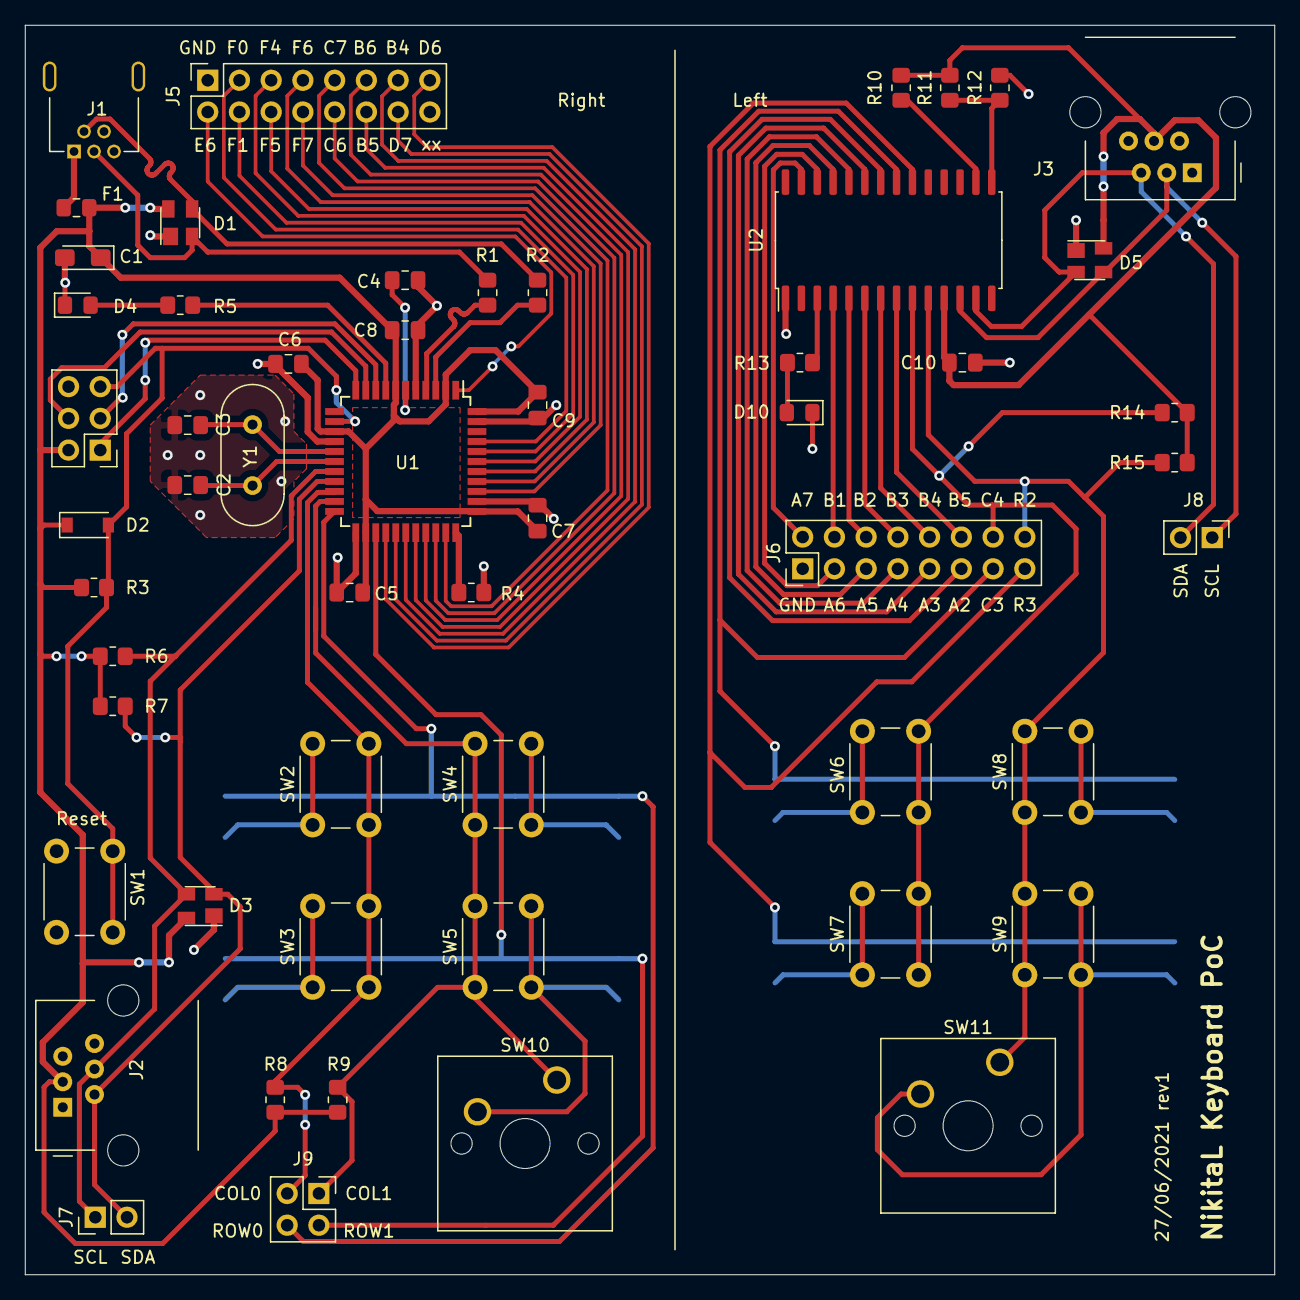
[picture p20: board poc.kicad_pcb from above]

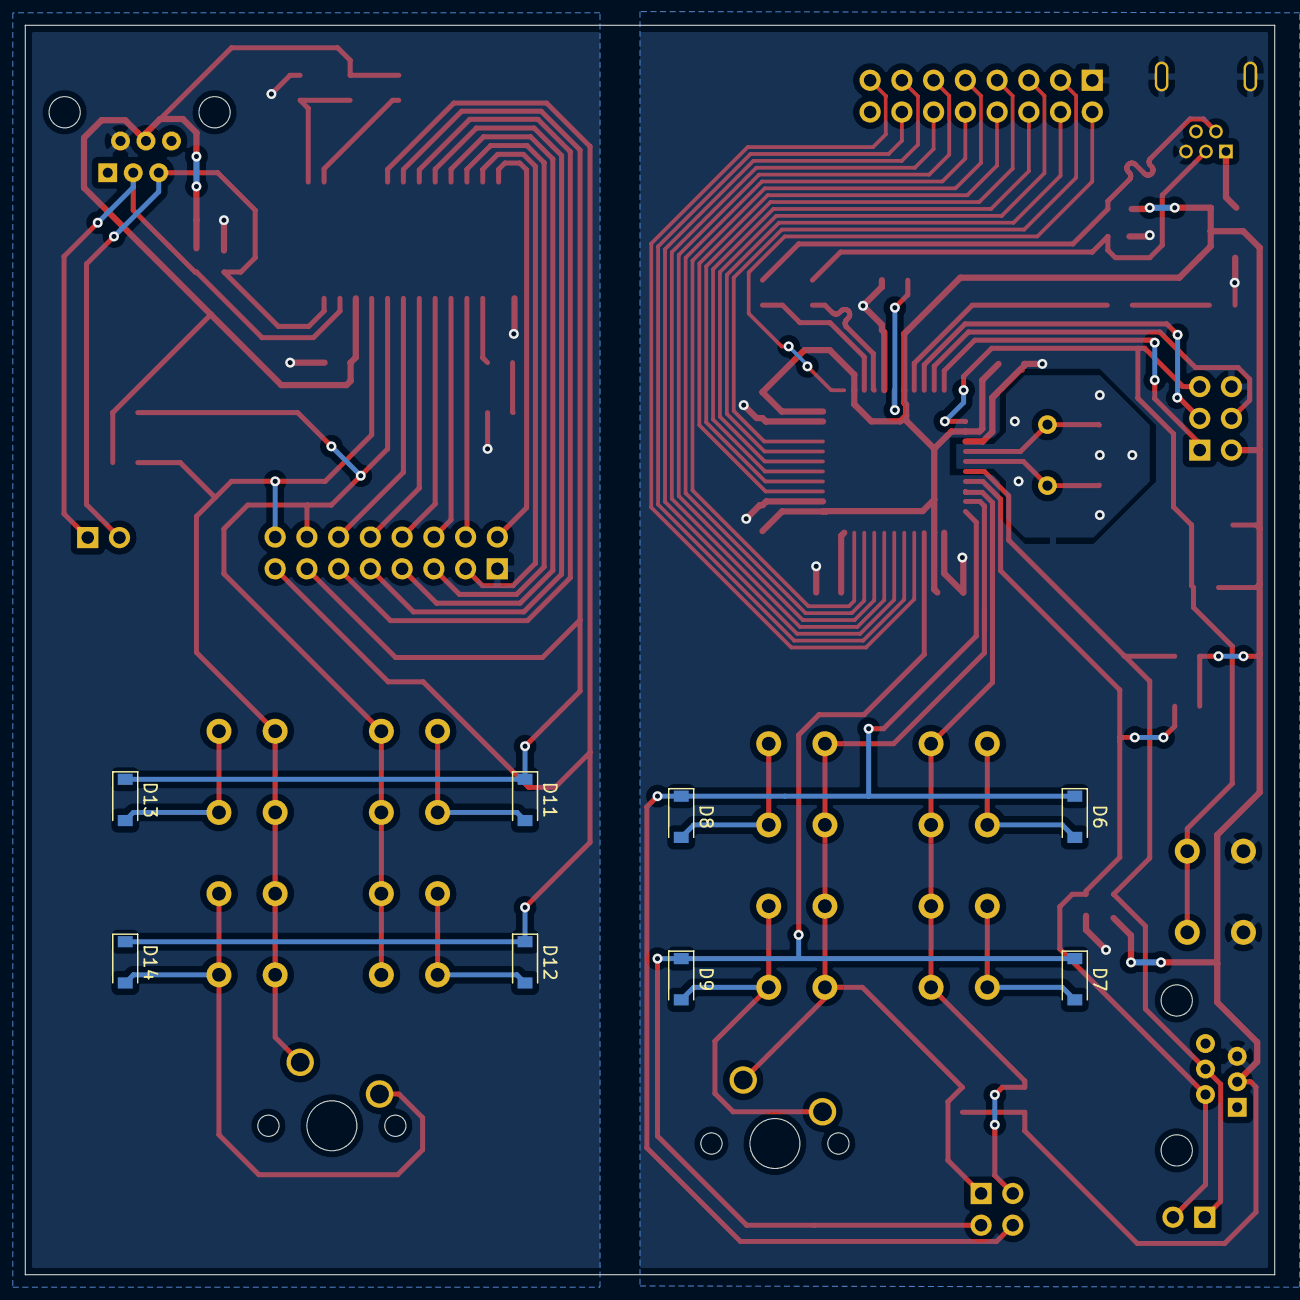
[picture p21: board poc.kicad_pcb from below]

Board: 2 copper layers, 100.0 x 100.0 mm, 63 parts (8 on the bottom side), 68 nets.

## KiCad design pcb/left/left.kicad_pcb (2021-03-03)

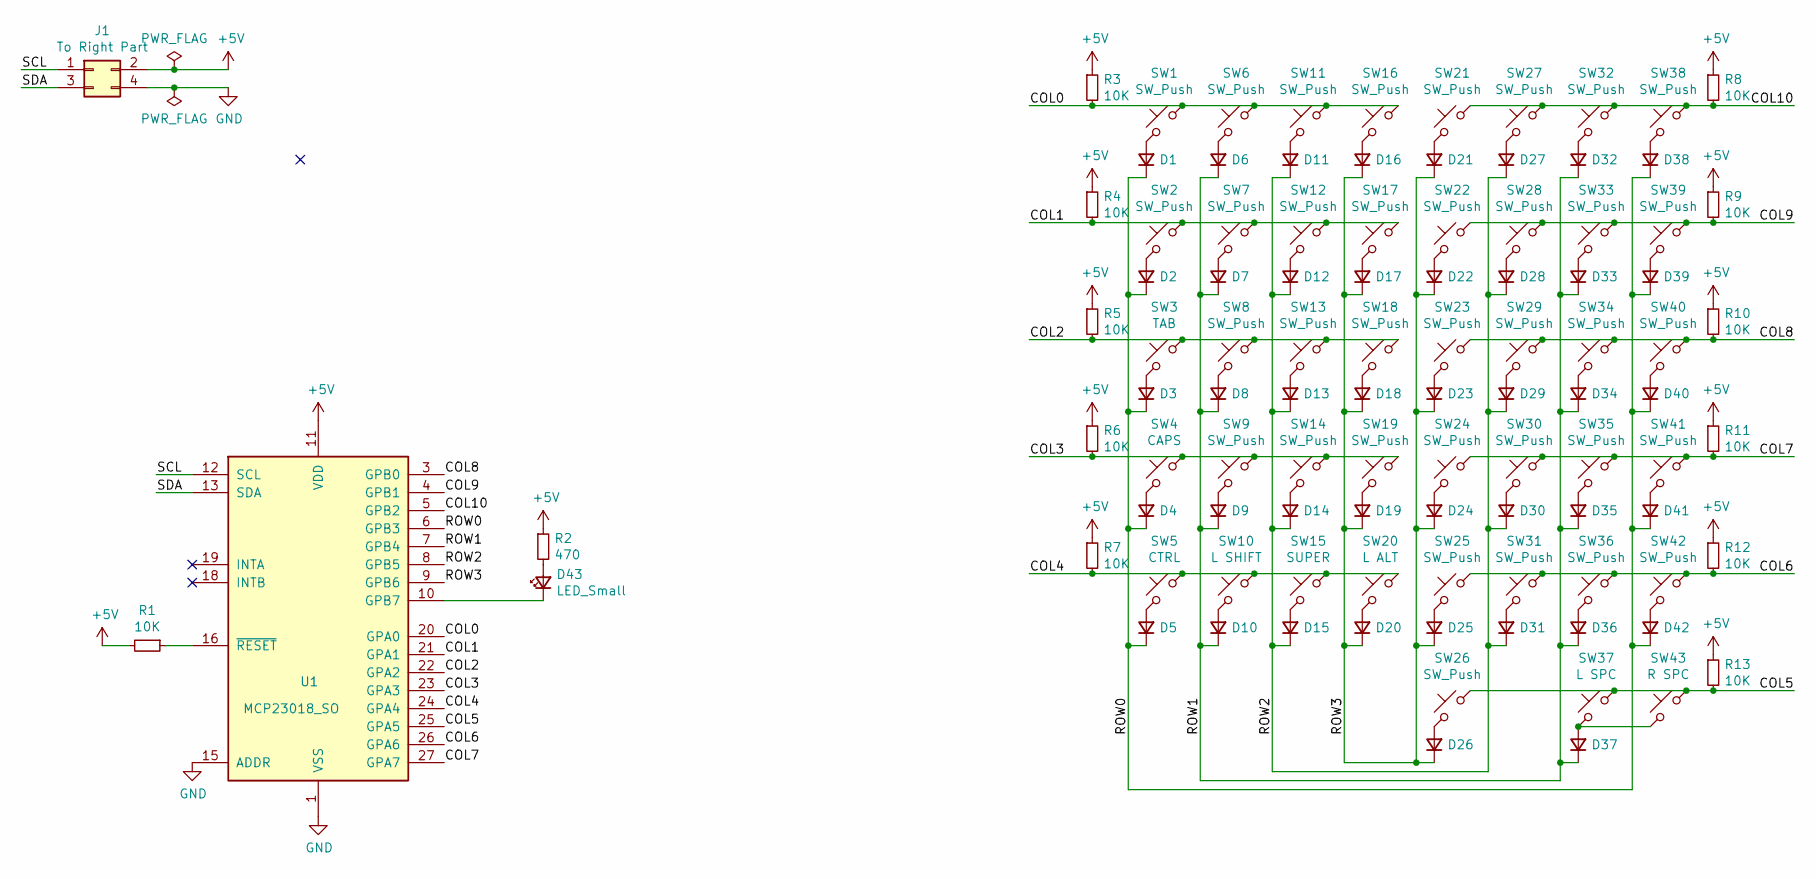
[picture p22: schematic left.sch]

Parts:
D1, D2, D3, D4, D5, D6, D7, D8, D9, D10, D11, D12, D13, D14, D15, D16, D17, D18, D19, D20, D21, D22, D23, D24, D25, D26, D27, D28, D29, D30, D31, D32, D33, D34, D35, D36, D37, D38, D39, D40, D41, D42: D_Small; D_SOD-123
D43: LED_Small; LED_0805_2012Metric_Pad1.15x1.40mm_HandSolder
J1: To Right Part; PinHeader_2x02_P2.54mm_Vertical
R1, R3, R4, R5, R6, R7, R8, R9, R10, R11, R12, R13: 10K; R_0805_2012Metric_Pad1.20x1.40mm_HandSolder
R2: 470; R_0805_2012Metric_Pad1.20x1.40mm_HandSolder
SW1, SW2, SW6, SW7, SW8, SW9, SW11, SW12, SW13, SW14, SW16, SW17, SW18, SW19, SW21, SW22, SW23, SW24, SW25, SW26, SW27, SW28, SW29, SW30, SW31, SW32, SW33, SW34, SW35, SW36, SW38, SW39, SW40, SW41, SW42: SW_Push; SW_Cherry_MX_1.00u_PCB
SW3: TAB; SW_Cherry_MX_1.50u_PCB
SW4: CAPS; SW_Cherry_MX_1.75u_PCB
SW5: CTRL; SW_Cherry_MX_1.25u_PCB
SW10: L SHIFT; SW_Cherry_MX_2.25u_PCB
SW15: SUPER; SW_Cherry_MX_1.25u_PCB
SW20: L ALT; SW_Cherry_MX_1.25u_PCB
SW37: L SPC; SW_Cherry_MX_2.75u_PCB
SW43: R SPC; SW_Cherry_MX_2.25u_PCB
U1: MCP23018_SO; SOIC-28W_7.5x17.9mm_P1.27mm

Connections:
+5V: J1.2, R1.2, R2.1, R3.1, R4.1, R5.1, R6.1, R7.1, R8.1, R9.1, R10.1, R11.1, R12.1, R13.1, U1.11 (VDD)
/COL0: R3.2, SW1.1, SW6.1, SW11.1, SW16.1, U1.20 (GPA0)
/COL1: R4.2, SW2.1, SW7.1, SW12.1, SW17.1, U1.21 (GPA1)
/COL2: R5.2, SW3.1, SW8.1, SW13.1, SW18.1, U1.22 (GPA2)
/COL3: R6.2, SW4.1, SW9.1, SW14.1, SW19.1, U1.23 (GPA3)
/COL4: R7.2, SW5.1, SW10.1, SW15.1, SW20.1, U1.24 (GPA4)
/COL5: R13.2, SW26.1, SW37.1, SW43.1, U1.25 (GPA5)
/COL6: R12.2, SW25.1, SW31.1, SW36.1, SW42.1, U1.26 (GPA6)
/COL7: R11.2, SW24.1, SW30.1, SW35.1, SW41.1, U1.27 (GPA7)
/COL8: R10.2, SW23.1, SW29.1, SW34.1, SW40.1, U1.3 (GPB0)
/COL9: R9.2, SW22.1, SW28.1, SW33.1, SW39.1, U1.4 (GPB1)
/COL10: R8.2, SW21.1, SW27.1, SW32.1, SW38.1, U1.5 (GPB2)
/ROW0: D1.1 (K), D2.1 (K), D3.1 (K), D4.1 (K), D5.1 (K), D38.1 (K), D39.1 (K), D40.1 (K), D41.1 (K), D42.1 (K), U1.6 (GPB3)
/ROW1: D6.1 (K), D7.1 (K), D8.1 (K), D9.1 (K), D10.1 (K), D32.1 (K), D33.1 (K), D34.1 (K), D35.1 (K), D36.1 (K), D37.1 (K), U1.7 (GPB4)
/ROW2: D11.1 (K), D12.1 (K), D13.1 (K), D14.1 (K), D15.1 (K), D27.1 (K), D28.1 (K), D29.1 (K), D30.1 (K), D31.1 (K), U1.8 (GPB5)
/ROW3: D16.1 (K), D17.1 (K), D18.1 (K), D19.1 (K), D20.1 (K), D21.1 (K), D22.1 (K), D23.1 (K), D24.1 (K), D25.1 (K), D26.1 (K), U1.9 (GPB6)
/SCL: J1.1, U1.12 (SCL)
/SDA: J1.3, U1.13 (SDA)
GND: J1.4, U1.1 (VSS), U1.15 (ADDR)
unnamed: D1.2 (A), SW1.2
unnamed: D2.2 (A), SW2.2
unnamed: D3.2 (A), SW3.2
unnamed: D4.2 (A), SW4.2
unnamed: D5.2 (A), SW5.2
unnamed: D6.2 (A), SW6.2
unnamed: D7.2 (A), SW7.2
unnamed: D8.2 (A), SW8.2
unnamed: D9.2 (A), SW9.2
unnamed: D10.2 (A), SW10.2
unnamed: D11.2 (A), SW11.2
unnamed: D12.2 (A), SW12.2
unnamed: D13.2 (A), SW13.2
unnamed: D14.2 (A), SW14.2
unnamed: D15.2 (A), SW15.2
unnamed: D16.2 (A), SW16.2
unnamed: D17.2 (A), SW17.2
unnamed: D18.2 (A), SW18.2
unnamed: D19.2 (A), SW19.2
unnamed: D20.2 (A), SW20.2
unnamed: D21.2 (A), SW21.2
unnamed: D22.2 (A), SW22.2
unnamed: D23.2 (A), SW23.2
unnamed: D24.2 (A), SW24.2
unnamed: D25.2 (A), SW25.2
unnamed: D26.2 (A), SW26.2
unnamed: D27.2 (A), SW27.2
unnamed: D28.2 (A), SW28.2
unnamed: D29.2 (A), SW29.2
unnamed: D30.2 (A), SW30.2
unnamed: D31.2 (A), SW31.2
unnamed: D32.2 (A), SW32.2
unnamed: D33.2 (A), SW33.2
unnamed: D34.2 (A), SW34.2
unnamed: D35.2 (A), SW35.2
unnamed: D36.2 (A), SW36.2
unnamed: D37.2 (A), SW37.2, SW43.2
unnamed: D38.2 (A), SW38.2
unnamed: D39.2 (A), SW39.2
unnamed: D40.2 (A), SW40.2
unnamed: D41.2 (A), SW41.2
unnamed: D42.2 (A), SW42.2
unnamed: D43.1 (K), U1.10 (GPB7)
unnamed: D43.2 (A), R2.2
unnamed: R1.1, U1.16 (~RESET)

Board: 2 copper layers, 101 parts (43 on the bottom side), 64 nets, no tracks yet.

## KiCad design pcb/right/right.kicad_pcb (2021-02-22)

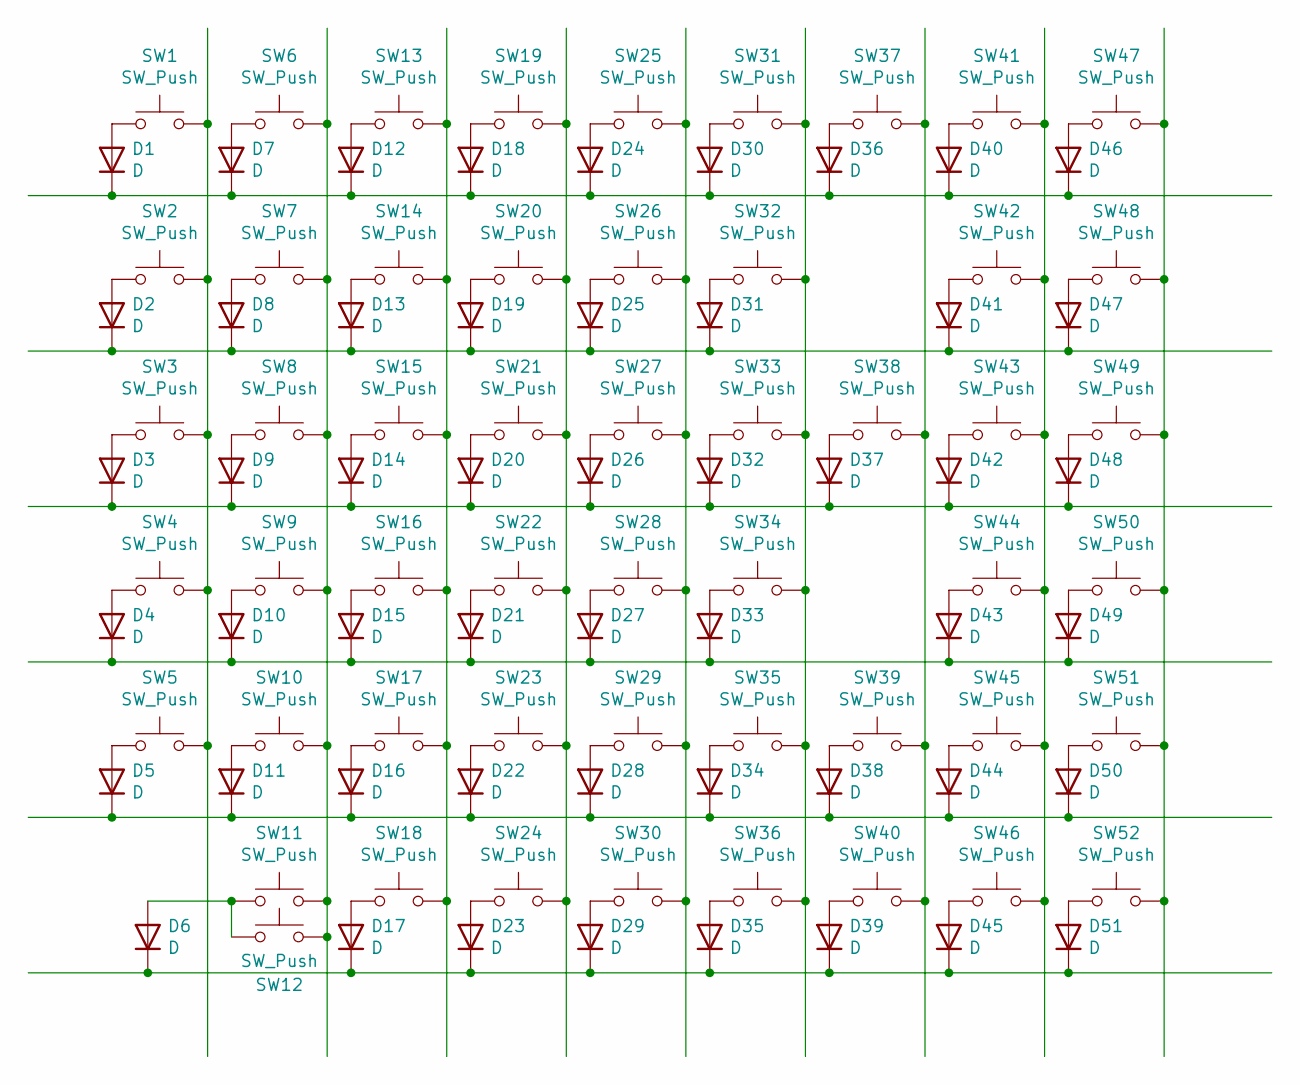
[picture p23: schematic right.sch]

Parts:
D1, D2, D3, D4, D5, D6, D7, D8, D9, D10, D11, D12, D13, D14, D15, D16, D17, D18, D19, D20, D21, D22, D23, D24, D25, D26, D27, D28, D29, D30, D31, D32, D33, D34, D35, D36, D37, D38, D39, D40, D41, D42, D43, D44, D45, D46, D47, D48, D49, D50, D51: D; D_SOD-123
SW1, SW2, SW3, SW4, SW5, SW6, SW7, SW8, SW9, SW10, SW13, SW14, SW15, SW16, SW17, SW18, SW19, SW20, SW21, SW22, SW23, SW24, SW25, SW26, SW27, SW28, SW29, SW30, SW31, SW32, SW33, SW34, SW35, SW36, SW37, SW38, SW40, SW41, SW45, SW46, SW47, SW48, SW49, SW50, SW51, SW52: SW_Push; SW_Cherry_MX_1.00u_PCB
SW11, SW44: SW_Push; SW_Cherry_MX_2.25u_PCB
SW12: SW_Push; SW_Cherry_MX_2.75u_PCB
SW39: SW_Push; SW_Cherry_MX_1.75u_PCB
SW42: SW_Push; SW_Cherry_MX_2.00u_PCB
SW43: SW_Push; SW_Cherry_MX_1.50u_PCB

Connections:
unnamed: D1.1 (K), D7.1 (K), D12.1 (K), D18.1 (K), D24.1 (K), D30.1 (K), D36.1 (K), D40.1 (K), D46.1 (K)
unnamed: D1.2 (A), SW1.1
unnamed: D2.2 (A), SW2.1
unnamed: D3.2 (A), SW3.1
unnamed: D4.2 (A), SW4.1
unnamed: D5.2 (A), SW5.1
unnamed: D6.2 (A), SW11.1, SW12.1
unnamed: D7.2 (A), SW6.1
unnamed: D8.2 (A), SW7.1
unnamed: D9.2 (A), SW8.1
unnamed: D4.1 (K), D10.1 (K), D15.1 (K), D21.1 (K), D27.1 (K), D33.1 (K), D43.1 (K), D49.1 (K)
unnamed: D10.2 (A), SW9.1
unnamed: D5.1 (K), D11.1 (K), D16.1 (K), D22.1 (K), D28.1 (K), D34.1 (K), D38.1 (K), D44.1 (K), D50.1 (K)
unnamed: D11.2 (A), SW10.1
unnamed: D12.2 (A), SW13.1
unnamed: D2.1 (K), D8.1 (K), D13.1 (K), D19.1 (K), D25.1 (K), D31.1 (K), D41.1 (K), D47.1 (K)
unnamed: D13.2 (A), SW14.1
unnamed: D3.1 (K), D9.1 (K), D14.1 (K), D20.1 (K), D26.1 (K), D32.1 (K), D37.1 (K), D42.1 (K), D48.1 (K)
unnamed: D14.2 (A), SW15.1
unnamed: D15.2 (A), SW16.1
unnamed: D16.2 (A), SW17.1
unnamed: D6.1 (K), D17.1 (K), D23.1 (K), D29.1 (K), D35.1 (K), D39.1 (K), D45.1 (K), D51.1 (K)
unnamed: D17.2 (A), SW18.1
unnamed: D18.2 (A), SW19.1
unnamed: D19.2 (A), SW20.1
unnamed: D20.2 (A), SW21.1
unnamed: D21.2 (A), SW22.1
unnamed: D22.2 (A), SW23.1
unnamed: D23.2 (A), SW24.1
unnamed: D24.2 (A), SW25.1
unnamed: D25.2 (A), SW26.1
unnamed: D26.2 (A), SW27.1
unnamed: D27.2 (A), SW28.1
unnamed: D28.2 (A), SW29.1
unnamed: D29.2 (A), SW30.1
unnamed: D30.2 (A), SW31.1
unnamed: D31.2 (A), SW32.1
unnamed: D32.2 (A), SW33.1
unnamed: D33.2 (A), SW34.1
unnamed: D34.2 (A), SW35.1
unnamed: D35.2 (A), SW36.1
unnamed: D36.2 (A), SW37.1
unnamed: D37.2 (A), SW38.1
unnamed: D38.2 (A), SW39.1
unnamed: D39.2 (A), SW40.1
unnamed: D40.2 (A), SW41.1
unnamed: D41.2 (A), SW42.1
unnamed: D42.2 (A), SW43.1
unnamed: D43.2 (A), SW44.1
unnamed: D44.2 (A), SW45.1
unnamed: D45.2 (A), SW46.1
unnamed: D46.2 (A), SW47.1
unnamed: D47.2 (A), SW48.1
unnamed: D48.2 (A), SW49.1
unnamed: D49.2 (A), SW50.1
unnamed: D50.2 (A), SW51.1
unnamed: D51.2 (A), SW52.1
unnamed: SW1.2, SW2.2, SW3.2, SW4.2, SW5.2
unnamed: SW6.2, SW7.2, SW8.2, SW9.2, SW10.2, SW11.2, SW12.2
unnamed: SW13.2, SW14.2, SW15.2, SW16.2, SW17.2, SW18.2
unnamed: SW19.2, SW20.2, SW21.2, SW22.2, SW23.2, SW24.2
unnamed: SW25.2, SW26.2, SW27.2, SW28.2, SW29.2, SW30.2
unnamed: SW31.2, SW32.2, SW33.2, SW34.2, SW35.2, SW36.2
unnamed: SW37.2, SW38.2, SW39.2, SW40.2
unnamed: SW41.2, SW42.2, SW43.2, SW44.2, SW45.2, SW46.2
unnamed: SW47.2, SW48.2, SW49.2, SW50.2, SW51.2, SW52.2

Board: 2 copper layers, 103 parts (51 on the bottom side), 66 nets, no tracks yet.

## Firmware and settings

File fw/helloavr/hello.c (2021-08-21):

#ifndef F_CPU
#define F_CPU 16000000UL // 16 MHz clock speed
#endif

#include <avr/io.h>
#include <avr/power.h>
#include <avr/wdt.h>
#include <util/delay.h>

#define TWSR_TWS (TWSR & ~(_BV(TWPS0) | _BV(TWPS1)))

#define IODIRA (0x00)
#define IODIRB (0x01)
#define IPOLA (0x02)
#define IPOLB (0x03)
#define GPPUA (0x0c)
#define GPPUB (0x0d)
#define GPIOA (0x12)
#define GPIOB (0x13)

static void led_init()
{
  PORTB &= ~_BV(PIN0);
  DDRB |= _BV(PIN0);
}

static void led_blink(int times)
{
  static const int DELAY = 200;
  while (times-- > 0)
  {
    PORTB |= _BV(PIN0);
    _delay_ms(DELAY);
    PORTB &= ~_BV(PIN0);
    _delay_ms(DELAY);
  }
}

static void led_error()
{
  static const int DELAY = 50;
  while (1)
  {
    PORTB |= _BV(PIN0);
    _delay_ms(DELAY);
    PORTB &= ~_BV(PIN0);
    _delay_ms(DELAY);
  }
}

static void twi_init()
{
  // No internal pullup for TWI
  PORTD &= ~_BV(PIN0);
  PORTD &= ~_BV(PIN1);
  // No prescaler
  TWSR &= ~(_BV(TWPS0) | _BV(TWPS1));
  // OK bitrate
  TWBR = 0x20;
  // Enable
  TWCR = _BV(TWEN);
}

static void twi_write(const uint8_t * data, int size)
{
  // Wait for a previous STOP condition to clear
  loop_until_bit_is_clear(TWCR, TWSTO);

  // START condition
  TWCR = _BV(TWSTA) | _BV(TWINT) | _BV(TWEN);
  loop_until_bit_is_set(TWCR, TWINT);
  if (TWSR_TWS != 0x08 && TWSR_TWS != 0x10) led_error();

  // SLA+W
  TWDR = (0x20 << 1) | 0;
  TWCR = _BV(TWINT) | _BV(TWEN);
  loop_until_bit_is_set(TWCR, TWINT);
  if (TWSR_TWS != 0x18) led_error();

  // Data
  for (int i = 0; i < size; i++)
  {
    TWDR = data[i];
    TWCR = _BV(TWINT) | _BV(TWEN);
    loop_until_bit_is_set(TWCR, TWINT);
    if (TWSR_TWS != 0x28) led_error();
  }

  // STOP condition
  TWCR = _BV(TWSTO) | _BV(TWINT) | _BV(TWEN);
}

static void twi_read(uint8_t * data, int size)
{
  // Wait for a previous STOP condition to clear
  loop_until_bit_is_clear(TWCR, TWSTO);

  // START condition
  TWCR = _BV(TWSTA) | _BV(TWINT) | _BV(TWEN);
  loop_until_bit_is_set(TWCR, TWINT);
  if (TWSR_TWS != 0x08 && TWSR_TWS != 0x10) led_error();

  // SLA+R
  TWDR = (0x20 << 1) | 1;
  TWCR = _BV(TWINT) | _BV(TWEN);
  loop_until_bit_is_set(TWCR, TWINT);
  if (TWSR_TWS != 0x40) led_error();

  // Data
  for (int i = 0; i < size; i++)
  {
    int last = i == size - 1;
    TWCR = (last ? 0 : _BV(TWEA)) | _BV(TWINT) | _BV(TWEN);
    loop_until_bit_is_set(TWCR, TWINT);
    if (last ? (TWSR_TWS != 0x58) : (TWSR_TWS != 0x50)) led_error();
    data[i] = TWDR;
  }

  // STOP condition
  TWCR = _BV(TWSTO) | _BV(TWINT) | _BV(TWEN);
}

static void mcp_init()
{
  // Assume device is in IOCON.BANK=0

  // Make sure writes increment pointer
  uint8_t enable_seqop[2] = {0xA, 0};
  twi_write(enable_seqop, sizeof(enable_seqop));

  // First thing, flip direction to input
  uint8_t init1[1 + 0xa] = {0, 0xff, 0xff};
  twi_write(init1, sizeof(init1));

  // Skip IOCON

  // Zero the rest
  uint8_t init2[1 + 0xa] = {0xC};
  twi_write(init2, sizeof(init2));
}

static void mcp_write(uint8_t reg, uint8_t value)
{
  uint8_t data[2] = {reg, value};
  twi_write(data, sizeof(data));
}

static uint8_t mcp_read(uint8_t reg)
{
  uint8_t addr[1] = {reg};
  twi_write(addr, sizeof(addr));
  uint8_t value[1];
  twi_read(value, sizeof(value));
  return value[0];
}

int main(void)
{
  // DFU enables WDT
  MCUSR &= ~_BV(WDRF);
  wdt_disable();

  clock_prescale_set(clock_div_1);

  DDRB = DDRC = DDRD = DDRE = DDRF = 0;
  PORTB = PORTC = PORTD = PORTE = PORTF = ~0;

  led_init();
  twi_init();
  mcp_init();

  // COL0/COL1 are inputs with pullup
  DDRD &= ~(_BV(PIN2) | _BV(PIN3));
  PORTD |= _BV(PIN2) | _BV(PIN3);

  // ROW0/ROW1 are outputs pulled low
  DDRD |= _BV(PIN4) | _BV(PIN5);
  PORTD |= _BV(PIN4) | _BV(PIN5);

  mcp_write(GPPUB, 0b11000001); // Pullup on columns and LED
  mcp_write(IPOLB, 0b11000000); // 1 means ground
  mcp_write(GPIOA, 0b11); // Disconnect rows from ground
  mcp_write(IODIRA, ~0b11); // Output on rows
  mcp_write(IODIRB, ~0b1); // Output on LED

  // Light show
  for (int i = 0; i < 5; i++)
  {
    PORTB |= _BV(PIN0);
    mcp_write(GPIOB, 0b0);
    _delay_ms(150);

    PORTB &= ~_BV(PIN0);
    mcp_write(GPIOB, 0b1);
    _delay_ms(150);
  }
  mcp_write(GPIOB, 0b0);

  while (1)
  {
    static const int SCAN_DELAY = 1;
    uint8_t result;

    // Scan ROW 0 and ROW 2
    PORTD &= ~_BV(PIN5);
    mcp_write(GPIOA, 0b01);
    _delay_ms(SCAN_DELAY);

    if ((PIND & _BV(PIN2)) == 0) led_blink(2);
    if ((PIND & _BV(PIN3)) == 0) led_blink(4);
    result = mcp_read(GPIOB);
    if (result & 0b01000000) led_blink(6);
    if (result & 0b10000000) led_blink(8);
    PORTD |= _BV(PIN5);

    // Scan ROW 1 and ROW 3
    PORTD &= ~_BV(PIN4);
    mcp_write(GPIOA, 0b10);
    _delay_ms(SCAN_DELAY);

    if ((PIND & _BV(PIN2)) == 0) led_blink(3);
    if ((PIND & _BV(PIN3)) == 0) led_blink(5);
    result = mcp_read(GPIOB);
    if (result & 0b01000000) led_blink(7);
    if (result & 0b10000000) led_blink(9);
    PORTD |= _BV(PIN4);
  }
}

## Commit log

2020-10-17 plate: Generate
    [swillkb_split.dxf, swillkb_split_offset.dxf]
2020-10-25 pcb: Right schematic
    [right.kicad_pcb, right.sch]
2020-10-25 right: Assign footprint + netlist
    [right.sch]
2020-10-25 pcb: Right key layout
    [right.sch]
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2020-11-07 pcb: right: Shrink spacebar stab hole
    [right.kicad_pcb]
2020-11-07 pcb: right: Update Design Rules to JLCPCB
    [right.kicad_pcb]
2020-11-07 pcb: right: diodes
    [right.kicad_pcb]
2021-02-22 pcb: right: Revert small spacebar hole
    [right.kicad_pcb]
2021-02-24 pcb: right: Power to MCU
    [right.sch]
2021-02-25 pcb: Right: Reset
    [right.sch]
2021-02-26 pcb: right: ICSP, I2C
    [right.sch]
2021-02-27 pcb: right: Finish schematics
    [right.sch]
2021-02-27 pcb: right: annotate
    [right.sch]
2021-02-27 pcb: right: PWR_FLAG for EDC
    [right.sch]
2021-02-27 pcb: right: Footprint for ICSP and left part connector
    [right.sch]
2021-03-01 pcb: right: pullup for keys and i2c
    [right.sch]
2021-03-01 pcb: left: matrix schematic
    [left.kicad_pcb, left.sch]
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2021-03-02 pcb: left: schema
    [left.sch]
2021-03-02 pcb: left: annotate
    [left.sch]
2021-03-02 pcb: left: assign footprints
    [left.sch]
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2021-03-02 pcb: left: Layout keys
    [left.kicad_pcb]
2021-03-03 pcb: left: JLCPCB design rules
    [left.kicad_pcb]
2021-03-05 pcb: right: fuse size
    [right.sch]
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2021-03-06 pcb: right: Tanatalum capacitor
    [right.sch]
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2021-03-06 pcb: poc: schematic
    [poc.kicad_pcb, poc.sch]
2021-03-06 pcb: poc: Assign footprints
    [poc.sch]
2021-03-09 pcb: poc: JLCPCB design rules
    [poc.kicad_pcb]
2021-03-30 pcb: poc: Some routing
    [poc.kicad_pcb, poc.sch]
2021-03-31 pcb: poc: Routed nabaz stuff
    [poc.kicad_pcb, poc.sch]
2021-04-01 pcb: poc: Routed buttons and breakout
    [poc.kicad_pcb, poc.sch]
2021-04-01 pcb: poc: Change 2x11 to 2x10 breakout
    [poc.kicad_pcb, poc.sch]
2021-04-01 pcb: poc: i2c breakout and crystal ground
    [poc.kicad_pcb, poc.sch]
2021-04-01 pcb: poc: MCP side layout
    [poc.kicad_pcb, poc.sch]
2021-04-01 pcb: poc: Finished?
    [poc.kicad_pcb, poc.sch]
2021-04-01 pcb: poc: silkscreen
    [poc.kicad_pcb]
2021-04-03 pcb: poc: Make USB track 0.25
    [poc.kicad_pcb]
2021-04-03 pcb: poc: Change track to 0.4mm
    [poc.kicad_pcb]
2021-04-03 pcb: poc: Space out left side
    [poc.kicad_pcb, poc.sch]
2021-06-17 pcb: poc: routed left side except breakout
    [poc.kicad_pcb]
2021-06-17 pcb: poc: Route left breakout
    [poc.kicad_pcb, poc.sch]
2021-06-17 pcb: poc: Make left breakout smaller
    [poc.kicad_pcb, poc.sch]
2021-06-27 pcb: poc: Silkscreen adjustment
    [poc.kicad_pcb]
2021-06-27 pcb: poc: Move stiching via for clock
    [poc.kicad_pcb]
2021-06-27 pcb: poc: Sign the PCB
    [poc.kicad_pcb]
2021-06-27 pcb: poc: Export gerbers
    [poc-B_Cu.gbl, poc-B_Mask.gbs, poc-B_Paste.gbp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]
2021-08-21 pcb: poc: annotate capacitor
    [poc.sch]
2021-09-05 pcb: Fix USB pinout
2021-09-05 pcb: slash_left: new project
    [slash_left.kicad_pcb, slash_left.sch]
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2021-09-06 pcb: slash_left: Schematic
    [slash_left.sch]
2021-09-06 pcb: slash_right: Start schematic
    [slash_right.kicad_pcb, slash_right.sch]
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2021-09-10 pcb: slash_right: General electronics
    [slash_right.sch]
2021-10-01 pcb: slash: Matrix schematic
    [slash_left.sch, slash_right.sch]
2021-10-08 pcb: slash_righ: Fill missing values
    [slash_right.sch]
2021-10-08 pcb: slash_right: Annotate
    [slash_right.sch]
2021-10-08 pcb: slash_right: Assign footprints
    [slash_right.sch]
2021-10-09 pcb: slash_right: Layout switches
    [slash_right.kicad_pcb]
2021-10-09 pcb: slash_righ: Place switches
    [slash_right.kicad_pcb, slash_right.sch]
2021-10-09 pcb: slash_right: rough layout
    [slash_right.kicad_pcb]
2021-10-09 pcb: slash_right: Add PWR symbol
    [slash_right.sch]
2021-10-10 plate: slash from swillkb
    [swillkb_slash.dxf]
2021-10-23 plate: slash: right
    [slash_right.dxf]
2021-10-23 pcb: slash: right: Start routing
    [slash_right.kicad_pcb]
2021-10-24 pcb: slash: right: Continue
    [slash_right.kicad_pcb]
2021-11-13 pcb: slash: Progress
    [slash_right.kicad_pcb, slash_right.sch]
2021-11-15 pcb: slash: more routing
    [slash_right.kicad_pcb, slash_right.sch]
2021-11-28 pcb: slash: right: Finish routing
    [slash_right.kicad_pcb, slash_right.sch]
2021-11-28 pcb: slash: right: Tune USB diff pair
    [slash_right.kicad_pcb]
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2021-12-02 pcb: slash: left: Assign footprints
    [slash_left.sch]
2021-12-12 pcb: slash: left: Routing
    [slash_left.kicad_pcb, slash_left.sch]
2021-12-15 pcb: slash: left: finish
    [slash_left.kicad_pcb, slash_left.sch]
2021-12-19 plate: slash: Rename file
    [slash_swillkb.dxf]
2021-12-19 pcb: slash: Silkscreen adjustment for production
    [slash_left.kicad_pcb, slash_right.kicad_pcb]
2021-12-19 pcb: slash: left: Add PWR flags
    [slash_left.sch]
2021-12-19 pcb: slash: Plot gerbers
    [slash_left-B_Cu.gbl, slash_left-B_Mask.gbs, slash_left-B_Paste.gbp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]
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2021-12-29 plate: slash: straighten edge
    [slash_left.dxf]
2022-01-19 plate: slash: Add holes for reset button and crystal
    [slash_right.dxf]
2022-06-02 plate: slash: Add production files
    [left_acryl_1_5_mm.dxf, left_acryl_4_mm.dxf, left_aluminum_1_5_mm.dxf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]
